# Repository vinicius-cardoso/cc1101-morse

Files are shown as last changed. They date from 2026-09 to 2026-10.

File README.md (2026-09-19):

# CC1101 Morse

A handheld Morse transceiver. Key it and the characters go out over 433 MHz;
leave it idle and it decodes what another unit sends back.

Press the key. The device times your dots and dashes, sounds a sidetone so you
hear what you send, keys the CC1101 in step, and prints the decoded letter over
serial. Point a second one at it and the two talk to each other.

The design goal is a board simple enough to make at home: **single layer,
through-hole only, no jumper wires**. There is no display — output is the buzzer
and the serial monitor — and that constraint is what keeps everything else
small.

<p align="center">
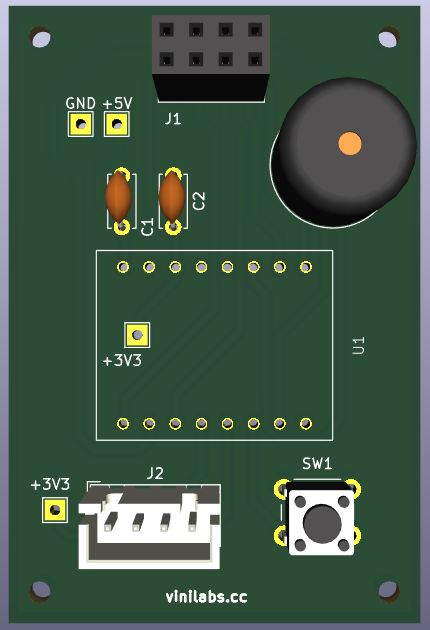
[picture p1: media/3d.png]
Rendered view of the assembled board
  
</p>

## Why it is simple

What the board carries is one module on a socket, a button, a buzzer, two
capacitors, two test points and two breakout headers — plus the MCU. None of it
surface-mount. That routes on a single face with no crossings to resolve.

| | |
|---|---|
| Layers | **1** |
| Vias | **0** |
| SMD parts | **0** |
| Jumper wires | **0** |
| Parts to solder | **11** |
| Display | serial + buzzer |

Zero SMD means the board can be hand-soldered from the underside with a plain
iron, and the fiber laser only ever etches one face — no two-sided
registration.

## Hardware

| Part | Role |
|---|---|
| ESP32-C3 Supermini | the brain — timing, decoding, radio, everything |
| CC1101 module | 433 MHz transceiver, socketed |
| Momentary key | Morse input |
| Passive buzzer | sidetone on transmit, audio on receive |
| SSD1306 OLED | *optional* — decoded text, plugs into `J2` |

Everything runs at **3.3 V**. The CC1101 is natively 3.3 V and so is the
ESP32-C3, so the supply is just the Supermini's onboard regulator — no boost
converter, no level shifter, no charge circuit.

### Pin budget — 8 of 13 GPIOs

| Function | Pins |
|---|---|
| CC1101 (SCK, MISO, MOSI, CS, GDO0, GDO2) | 6 |
| Morse key | 1 |
| Buzzer | 1 |
| **Total** | **8 — 5 spare** |
| *OLED (I²C, optional, off-board)* | *2 of the 5* |

See `docs/hardware.md` for the wiring detail.

## Transmit and receive

The CC1101 sends Morse as **OOK** — on-off keying, the carrier simply switched on
for a mark and off for a space. That is what Morse *is* on a radio, and it means
the transmitted signal is the key line itself: no packet format, no framing, no
preamble.

Receiving is the same idea backwards. The CC1101 is put in async serial mode,
where GDO0 goes high whenever the carrier is present, and the firmware times that
pin exactly the way it times the key. One decoder serves both directions.

> [!WARNING]
> **Never key the transmitter with the antenna unscrewed.** With nothing to
> radiate into, power reflects back into the PA and can damage it. For bench
> testing without emitting, use a 50 Ω dummy load in place of the whip.

> [!IMPORTANT]
> The legal position for 433 MHz short-range transmission in Brazil (ANATEL) has
> not been researched. Do that before transmitting outside a dummy load — see
> `docs/roadmap.md` phase 4.

## Power

USB-C, from the ESP32-C3 Supermini's own port. No battery, no charger, no boost,
no battery-sense divider — the board has **zero power components**.

Going portable later means wiring a cell and a TP4056 to the Supermini's
`5V`/`GND` pins. Nothing else changes, because nothing on the board wants more
than 3.3 V — so no boost converter is involved.

## On the bench

<p align="center">
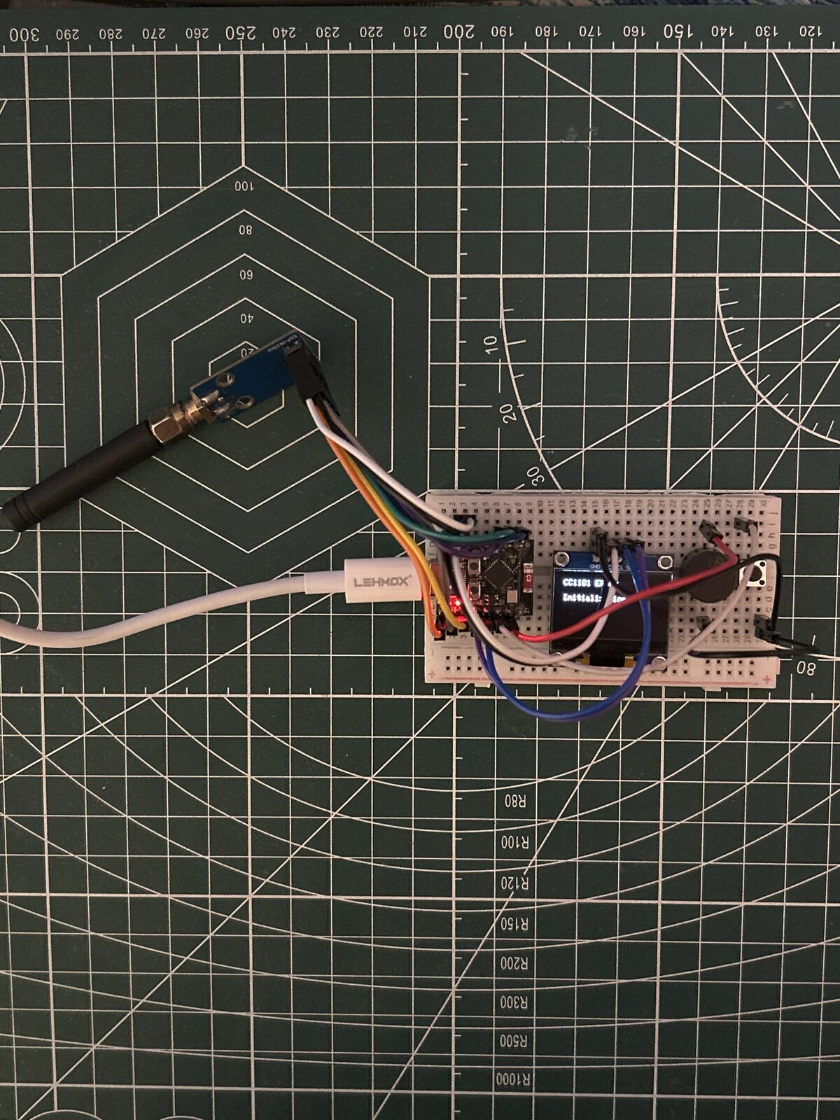
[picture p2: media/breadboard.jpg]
Breadboard prototype: ESP32-C3 Supermini, CC1101 with whip antenna, SSD1306 OLED, buzzer and key
  
</p>

The prototype, before the PCB exists: ESP32-C3 Supermini, the CC1101 with its
whip screwed on, a microswitch standing in for the key, a buzzer, and an
SSD1306 OLED on GPIO8/GPIO9.

**The OLED is optional.** `docs/decisions.md` §1 chose no display, and §7 kept
GPIO8/GPIO9 free so one could be added anyway; the board now brings them out on
`J2`, a 4-pin socket a module plugs straight into. The firmware supports a
display without requiring one:
`display.cpp` probes the I²C bus at startup, and if nothing answers, every
display call becomes a no-op. One binary runs with a screen and without.

## The board

<p align="center">
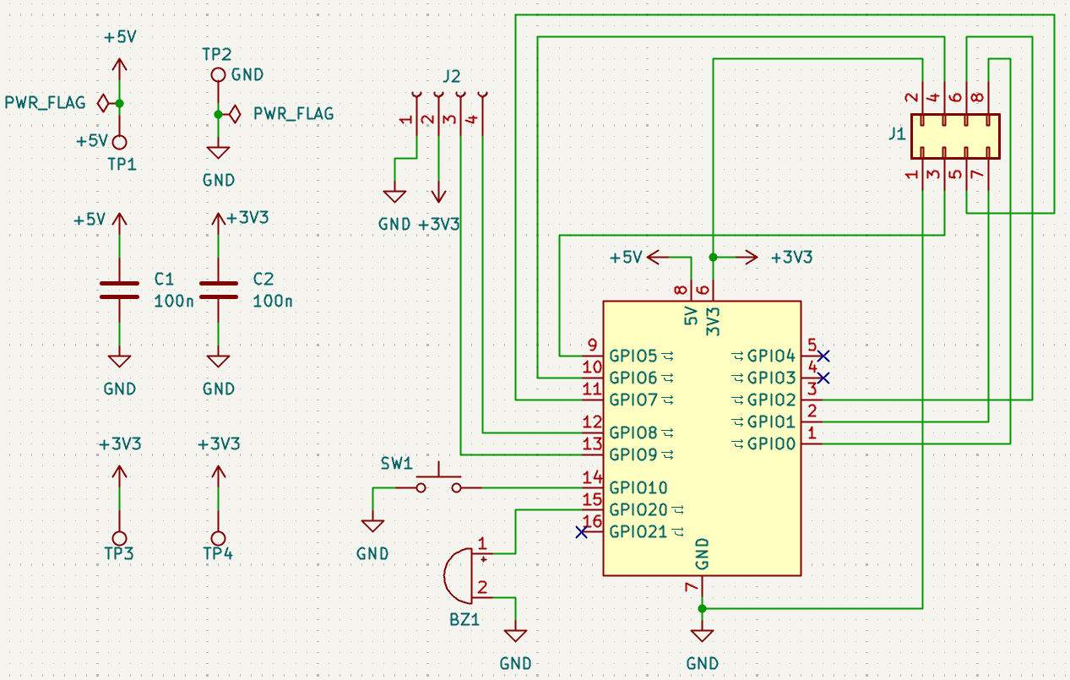
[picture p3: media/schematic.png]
Schematic: ESP32-C3 Supermini, CC1101 socket, key and buzzer
  
</p>

The CC1101 plugs into `J1`; `SW1` is the key and `BZ1` the buzzer. `C1`
decouples the `+5V` input to the Supermini's regulator, `C2` the `+3V3` rail at
the radio itself, and `TP1`/`TP2` are probe points for `+5V` and ground. `J2` is
a 4-pin socket for an optional display, with `TP3`/`TP4` a wire link that
completes its `+3V3` — see `docs/decisions.md` §14.

<p align="center">
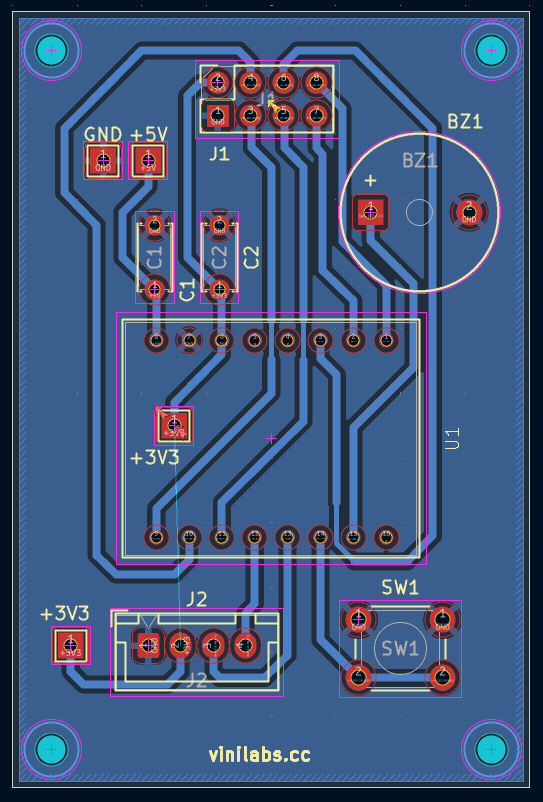
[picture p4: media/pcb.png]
PCB layout: single layer, through-hole, ground pour
  
</p>

All copper is on the **back** — no vias, no front-side traces. The stock is
single-sided, so components sit on the bare face and are soldered on the copper
face, which is the normal way to build through-hole on one layer.

Ground is the pour filling the board rather than a routed net, which is what
makes single layer work: the net that touches every part never has to be
threaded past the others. See `docs/decisions.md` §10.

Four M2 mounting holes, one per corner. Board is 40 × 60 mm.

## Repository layout

```text
.
├── bom/          # bill of materials
├── docs/         # design decisions, hardware notes
├── firmware/     # Arduino sketch (firmware/cc1101-morse/)
├── hardware/     # KiCad project, datasheets
├── mechanical/   # Onshape exports, case STEP/STL
└── media/        # reference images, photos
```

## Toolchain

- **KiCad** for the PCB (`hardware/kicad/`), exported to DXF for the laser —
  see `docs/fabrication.md`
- **Onshape** for the case, exported to `mechanical/`
- **Fiber laser** to engrave the copper
- **Arduino** for firmware (`firmware/cc1101-morse/`)

Keep editable sources as the source of truth: `.kicad_pro`, `.kicad_sch`,
`.kicad_pcb`, `.ino`, native CAD.

Generated manufacturing output lives in `exports/` and **is committed** —
`hardware/kicad/cc1101-morse/exports/` holds the DXF and drill files the laser
takes. They are derivatives, but a repo whose point is that you can make the
board should carry what the machine eats, without needing KiCad installed to
get it. Regenerate after any board change: `docs/fabrication.md` has the
commands.

## Status

**PCB done.** Routed by hand on one layer, no vias, ground poured — all copper
on the back, since the laminate is single-sided. DRC clean: 0 unconnected,
0 parity errors. DXF and drill files are exported for the laser; see
`docs/fabrication.md`, and **mind the mirror**. Not etched yet.

**The radio works.** On the breadboard the CC1101 answers over SPI
(`PARTNUM 0x0`, `VERSION 0x14`), and `send SOS SOS SOS` at 5 wpm was received on
an RTL-SDR in AM at 433.92 MHz. Key, decoder, buzzer and OLED all confirmed.

Next is phase 2 in `docs/roadmap.md` — a second unit, so two boards talk to each
other.

## Licence

GPL-3.0 — see `LICENSE`.

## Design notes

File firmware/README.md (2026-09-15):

# Firmware

Arduino sketch for the ESP32-C3 Supermini. Open
`cc1101-morse/cc1101-morse.ino` in the Arduino IDE, select **ESP32C3 Dev
Module**, and upload over USB.

> [!IMPORTANT]
> **Set `USB CDC On Boot` to `Enabled`.** It is *disabled* by default, and with
> it off `Serial` goes to the UART pins instead of the USB port — the sketch
> runs, prints into the void, and the serial monitor shows nothing at all. Every
> diagnostic in this firmware is a serial command, so without it you are blind.
>
> From the command line that is:
> ```sh
> arduino-cli compile --fqbn esp32:esp32:esp32c3:CDCOnBoot=cdc \
>   --libraries ~/hardware/arduino/libraries cc1101-morse
> arduino-cli upload -p /dev/ttyACM0 \
>   --fqbn esp32:esp32:esp32c3:CDCOnBoot=cdc cc1101-morse
> ```

The CC1101 is driven directly — no radio library. The **optional** OLED needs
`Adafruit_SSD1306` and `Adafruit_GFX`; if you do not have them, set
`DISPLAY_ENABLE 0` in `display.h` and the sketch builds without them.

## It runs with nothing attached

`radio.h` defaults to `RADIO_SIMULATE 1`: SPI is never touched and keying is
logged to the serial monitor instead of driving a chip. Key timing, decoding,
adaptive speed and the sidetone all work identically, so the whole firmware can
be developed and exercised on a bare Supermini — or on a Supermini with just a
button and a buzzer.

Set it to `0` once the CC1101 is wired.

You can also drive everything from the serial monitor with no key wired at all.
Type `help` for the command list.

## Files

| File | What it is |
|---|---|
| `cc1101-morse.ino` | main loop, serial commands, TX/RX arbitration |
| `morse_event.h` | the event vocabulary shared by both sources |
| `morse_tree.h` | the Morse tree, and letter ↔ code tables |
| `key.{h,cpp}` | debounce, dot/dash classification, adaptive speed |
| `radio.{h,cpp}` | CC1101 as an OOK carrier switch, both directions |
| `decoder.{h,cpp}` | events in, letters out |
| `sidetone.{h,cpp}` | the buzzer, at two pitches |
| `display.{h,cpp}` | optional SSD1306 OLED — absent by default |

## The shape of it

The design rests on one idea, and it is worth stating before reading the code:

**A dot is a dot whether a finger made it or a carrier did.**

`key.cpp` times a button. `radio.cpp` times a pin the CC1101 drives. Both emit
the same `MorseEvent` values, so `decoder.cpp` takes either one and never asks
which — the two decoder instances in the sketch are the same class with
different labels.

That is why receive cost so little to add. It is a second *producer*, not a
second decoder, and the tree walk, the letter commit, the gap handling and the
message buffer are all written once.

```
  key.cpp   ──┐
              ├──▶  MorseEvent  ──▶  decoder.cpp  ──▶  letters
  radio.cpp ──┘
```

## Why the event type has its own header

`morse_event.h` holds nothing but an enum, which looks like over-organisation
until you notice it is what lets `key.cpp` and `radio.cpp` stay strangers to
each other. Neither includes the other; both include the vocabulary. Putting
`MorseEvent` inside `key.h` would have made the radio depend on the key for no
reason other than where the type happened to be declared.

## The OLED is optional, and detected at runtime

The PCB has no display (`docs/decisions.md` §1), but GPIO8/GPIO9 were kept free
so one could be wired anyway (§7). `display.cpp` serves both cases from one
binary.

**It probes rather than assumes.** `Display::begin()` does a single-address I2C
probe at 0x3C. If nothing answers, `present_` stays false and every subsequent
call returns immediately — no retry loop, no timeout, no blocking. The buzzer and
serial output carry on exactly as before.

That is why there are no `#ifdef`s scattered through the sketch: the no-op path
is a runtime property of one object, not a compile-time variant of the whole
firmware. Plugging a screen into a finished board is a thing you can just do.

`DISPLAY_ENABLE 0` is a separate escape hatch, for building without the Adafruit
libraries installed. It compiles the module down to empty stubs.

**Wiring:** SDA to GPIO8, SCL to GPIO9, 3V3 and GND. Address 0x3C.

## Is your buzzer passive or active?

The firmware needs a **passive** buzzer — the kind that is just a piezo element
and plays whatever `tone()` drives it with. An active buzzer has its own
oscillator and plays one fixed note regardless, which collapses the 700 Hz and
550 Hz sidetones into the same sound and loses the distinction between what you
are sending and what is arriving.

They look identical, and listings rarely say which is which. Type `buzzer` at
the serial monitor:

| What you hear | What you have |
|---|---|
| pitch climbs 400 → 1200 Hz | **passive** — correct part |
| one steady note | **active** — wrong part |
| silence | not wired, or wired backwards |

It then plays 700 Hz and 550 Hz back to back. On a passive buzzer those are
obviously different notes; if they sound the same, it is active.

## Things worth knowing before changing it

**The radio stays in TX for `TX_HANG_MS` after you stop keying.** Switching modes
costs a calibration, so doing it per symbol would put that latency inside every
dot and smear the timing. The hang time trades a moment of deafness for clean
keying.

**The buzzer has an owner.** Whichever source keys it first holds it until it
releases. Letting your own key interrupt an incoming signal would chop up what
you are copying, which is backwards.

**Received marks shorter than `RADIO_RX_MIN_MARK_MS` are discarded.** 433 MHz is
full of garage doors and car fobs, and async mode has no sync word or CRC to
reject them. The threshold is a plausibility filter and nothing more — it cannot
tell a doorbell from a dash, only a 3 ms blip from a symbol. **It is a guess
until it has been tuned against the real band.**

**The message buffer is a fixed array, not a `String`.** This runs for hours
between resets, and heap fragmentation on a microcontroller is a slow, confusing
failure. When it fills, the oldest half is dropped.

## Testing without a second radio

Two units talking is the real test (see `docs/roadmap.md` phase 2), but before
that:

- `send SOS` transmits a known string, so a receiver — an SDR dongle, or a second
  unit — has something predictable to show.
- `status` reads `PARTNUM` / `VERSION` off the chip. **This is the first thing to
  run on newly wired hardware:** a sane answer (`0x00` / `0x14`) means SPI works,
  which separates wiring problems from radio problems. Anything else is almost
  always MISO/MOSI swapped or a module whose pin order differs from the assumed
  one.
- `power 0` drops TX power for bench work.

> [!WARNING]
> Fit a 50 Ω dummy load before any transmit test. Keying with nothing attached
> reflects power back into the PA and can damage it — and the whip cannot be used
> until the ANATEL question in `docs/roadmap.md` is settled.

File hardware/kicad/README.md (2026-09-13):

# KiCad

The KiCad project lives in `cc1101-morse/`, alongside `libraries/`.

`libraries/` holds the ESP32-C3 Supermini symbol and footprint, which the stock
KiCad libraries do not carry. Nothing else is needed from a custom library: the
CC1101 is a
socketed module represented by a generic `Conn_02x04_Odd_Even`, and everything
else is a stock KiCad part.

## Before drawing anything

Two things from `docs/hardware.md` that are easy to get wrong and expensive to
discover late:

1. **Check the CC1101 module's silkscreen** against the pin table in
   `docs/hardware.md` before routing. Pin order varies by module revision, and
   crossing VCC and GND destroys the module — on a board that is already etched.
   Check its **gender** too: the module on hand has male pins, so the board
   carries a female `PinSocket_2x04`. A `PinHeader` footprint has a different
   drill size and will not fit.

2. **This board is single-layer and through-hole only.** That is a design
   constraint, not a default to relax when routing gets awkward. If a net seems
   to need a jumper, the placement is wrong — see `docs/decisions.md` §3. The
   placement rules that make it work:

   - CC1101 socket at the board edge, SMA pointing outward.
   - Supermini directly beside it, so the six-trace SPI bundle is short.
   - Every ground-connected part at the perimeter; ground routes around the edge
     as a trace with short stubs inward, **not** as a pour.

## Footprints

All through-hole. The full table is in `docs/hardware.md` § KiCad reference —
`SW_PUSH_6mm`, `Buzzer_12x9.5RM7.6`, `PinSocket_2x04_P2.54mm_Vertical`,
`PinHeader_1x02_P2.54mm_Vertical`, `C_Disc_D5.0mm_W2.5mm_P5.00mm`.

## What to commit

Sources, not derivatives: `.kicad_pro`, `.kicad_sch`, `.kicad_pcb`, and any local
library files. The `.gitignore` already excludes backups, autosaves, the KiCad 10
`.history/` store, and generated gerbers — put manufacturing output in an
`exports/` directory if it needs keeping.

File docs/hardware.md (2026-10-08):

# Hardware notes

## Block diagram

```
   [KEY] ──────▶ ┌──────────────┐            ┌──────────┐
                 │  ESP32-C3    │ ──SPI───▶  │  CC1101  │ ──▶ SMA ──▶ whip
   [BUZZER] ◀─── │  Supermini   │ ◀──GDO0──▶ │  module  │
                 │              │ ╌╌GDO2╌╌╌  │          │   (wired, unused)
                 └──────────────┘            └──────────┘
                        │
                    USB-C (power + serial)
```

Everything on the board is 3.3 V. The ESP32-C3 Supermini's onboard regulator
supplies the CC1101 directly; there is no boost, no level shifter and no charge
circuit. That is the whole supply design.

The ESP32-C3 does all decision-making: key timing, dot/dash classification, tree
walking, letter identification, gap detection, radio keying, sidetone, and
decoding the received signal. The CC1101 is a dumb carrier switch in both
directions — see *OOK and why there is no packet format* below.

## Pin assignment (ESP32-C3 Supermini)

The Supermini breaks out GPIO 0–10, 20, 21 — 13 usable pins.

| GPIO | Function | Socket pin | Notes |
|---|---|---|---|
| 6 | CC1101 MOSI | 3 | |
| 5 | CC1101 SCK | 4 | |
| 2 | CC1101 MISO | 5 | |
| 7 | CC1101 GDO2 | 6 | wired, unused — see below |
| 0 | CC1101 GDO0 | 7 | TX key out / RX data in |
| 1 | CC1101 CSN | 8 | |
| 10 | Morse key | — | `INPUT_PULLUP`, active low |
| 20 | Buzzer | — | sidetone |

**Total: 8 of 13 — 5 spare (GPIO3, 4, 8, 9, 21).**

Listed in socket-pin order, because that is the order the wiring follows.

**The SPI assignment was chosen by the layout, not by the chip.** Every SPI line
here is bit-banged, so any GPIO serves, and the mapping was picked by searching
for the one whose traces do not cross. On a single-layer board a crossing is not
a nuisance — it is a trace that cannot be routed at all. See
`docs/decisions.md` §9.

### GDO2 is wired but not used

Nothing in the firmware reads it. Keying and carrier detection both run on
GDO0, and a second status pin adds nothing to the current design.

It is connected anyway because the pin cost nothing and the alternative was
discovering a use for it after the board was etched. A trace on an unpopulated
net is free; adding one to a finished single-layer board is not.

The use worth keeping in mind is **carrier sense** (`IOCFG2 = 0x0E`): the chip
asserts the pin when RSSI crosses a threshold, giving a hardware squelch. That
would let the receiver reject band noise *before* it reaches the timing code,
which is the weakest part of the RX path today — see *OOK and why there is no
packet format* and `RADIO_RX_MIN_MARK_MS` in `firmware/cc1101-morse/radio.h`.

Until then it is configured three-state (`0x2E`) and held as an input on the
ESP32-C3 side, so neither chip drives it.

GPIO8/GPIO9 are the strapping pins and the I²C defaults, and they stayed free
even though using them would have given a shorter route: the crossing-free search
was deliberately restricted to GPIO0–7 so an I²C peripheral — a small OLED for
the decoded text — remains possible. GPIO3, GPIO4 and GPIO21 are spare too.

These are final — the board is routed against them. Changing one now means
rewiring the schematic, re-routing, and editing `radio.h` to match.

## Power supply

**USB-C only.** The ESP32-C3 Supermini has a USB-C socket and an onboard 3.3 V
regulator. Plug it in and the board runs.

| Rail | Source | Feeds |
|---|---|---|
| `+3V3` | Supermini onboard regulator | CC1101, buzzer, key pull-up |
| `GND` | — | everything |

This is a genuine simplification rather than a deferral. Nothing on the board
wants more than 3.3 V, so there is no second rail to generate and no converter
to calibrate — the two failure modes that a mixed-voltage supply brings with it.

### Going portable later

There is **no battery header on the board** — the option was considered and left
off, since a cell can be soldered to the Supermini's own `5V`/`GND` pins if it is
ever wanted.

To go portable: a LiPo cell and a TP4056 charge module wire to these two
pins and nothing else changes. The CC1101 and ESP32-C3 are both 3.3 V, so a
3.7 V cell feeds `VIN` directly and the onboard regulator handles it — **no
boost converter needed**.

If that happens, add a resistor divider into a spare ADC pin (GPIO21 is free)
for a charge readout. Not on the board now:
an unpopulated divider is two more parts and two more traces for a feature that
does nothing while the board runs on USB.

## Power budget

There is no battery, so this only sizes the USB draw.

| Load | Draw |
|---|---|
| ESP32-C3 active | ~30 mA |
| CC1101 RX | ~16 mA |
| CC1101 TX @ 10 dBm | ~35 mA |
| Buzzer | ~20 mA |

- **Receive (idle listening): ~46 mA**
- **Transmit with sidetone: ~85 mA**

Any USB port supplies this without thinking about it. Worth recording because it
sets the cell size *if* the battery option is ever taken: 85 mA worst case means
a 1000 mAh cell runs roughly 12 hours. With no boost converter in the chain that
figure is real rather than derated.

## OOK and why there is no packet format

The CC1101 is normally used as a packet radio: you hand it bytes, it adds a
preamble, sync word and CRC, and the receiver hands bytes back. **None of that is
used here.**

Morse on a radio is **OOK** — on-off keying. The carrier is switched on for a
mark and off for a space, and the *timing of those switches is the message*.
There is nothing to packetise: the dot/dash structure already encodes everything,
and wrapping it in a frame would mean buffering the operator's keying, sending it
as a block, and replaying it at the far end. That destroys the thing that makes
Morse Morse, which is that it is live.

So the chip is configured as a carrier switch in both directions:

- **Transmit** — `MOD_FORMAT = OOK`, `GDO0` configured as the TX data input in
  async transparent mode. The firmware drives GDO0 high and the carrier comes on;
  drives it low and it goes off. Exactly like keying a transmitter.
- **Receive** — same mode, opposite direction. GDO0 becomes an output that
  follows the detected carrier, and the firmware times that pin with the same
  code that times the key.

One decoder serves both, which is the nice consequence: a received mark and a
keyed mark are the same event with a different source, so `decoder.cpp` does not
know or care which it is handling.

### Register settings that matter

| Register | Value | Why |
|---|---|---|
| `MDMCFG2` | `0x30` | OOK modulation, no sync word, no Manchester |
| `PKTCTRL0` | `0x32` | async serial mode — no packet engine at all |
| `IOCFG0` | `0x0D` (RX) / `0x2E` (TX) | GDO0 = serial data out / high-impedance for TX input |
| `IOCFG2` | `0x2E` | GDO2 three-state — wired to GPIO7 but unused |
| `FREQ2/1/0` | 433.92 MHz | the band centre |
| `PATABLE` | `0xC0` | +10 dBm; lower it for bench work |

The full init table lives in `firmware/cc1101-morse/radio.cpp` — that is the
authoritative copy, and it carries per-register comments.

> [!NOTE]
> Async mode means **no error correction and no addressing**. Anything on the
> channel keys the receiver, including garage doors, weather stations and car
> fobs, which are all over 433 MHz. Expect noise-triggered garbage between real
> letters; `decoder.cpp` filters implausibly short marks, but it cannot
> distinguish a neighbour's doorbell from a deliberate dash.

## CC1101 module and antenna

The module is the **V2.0 SMA variant**, marked `433M`, with a gold SMA female
socket on the board edge. It ships with a short black whip antenna carrying a
male SMA plug, which **screws onto** that socket.

The antenna is therefore **detachable, not built in** — the two simply come in
the same bag. Nothing to buy, but the mechanical design has to account for it:

- The SMA socket sticks out from the module's edge and is rigid. It sets a hard
  constraint on where the CC1101 can sit inside the case.
- The case needs either an opening for the whip, or an internal antenna position
  with the whip removed. Antennas do not work well inside a sealed enclosure,
  especially near a copper ground plane.
- A panel-mount SMA extension (pigtail) is the usual fix: socket on the case
  wall, short coax to the module. Adds a part but frees the module's placement.
- The whip is removable, so it can be unscrewed for storage — worth designing for
  if the device is meant to be pocketable.

**Never key the transmitter with the antenna unscrewed.** With nothing to radiate
into, power reflects back into the PA and can damage it. For bench testing
without emitting, use a 50 Ω dummy load in place of the whip.

### The module is socketed, not soldered

The CC1101 is removable. It is an expensive part relative to the rest of the
board, it is the part most likely to be swapped (different band, different module
revision), and it carries the rigid SMA connector that constrains the case — all
reasons to keep it removable.

**The module has male pins, so the board carries a female socket** (`J1`, a 2×4
pin socket). The module plugs down into it. Worth stating explicitly because the
two footprints have different drill diameters and are not interchangeable — the
wrong one means a board that is etched and drilled but will not accept the part:

| | Board carries | Drill |
|---|---|---|
| `PinSocket_2x04` | a female socket body — **this board** | larger |
| `PinHeader_2x04` | male pins | smaller |

Check the module in hand rather than trusting this table: revisions vary, and
some ship with female headers instead.

| Socket pad | CC1101 | ESP32-C3 |
|---|---|---|
| 1 | GND | `GND` |
| 2 | VCC | `+3V3` |
| 3 | GDO0 | GPIO5 |
| 4 | CSN | GPIO6 |
| 5 | SCK | GPIO7 |
| 6 | MOSI | GPIO2 |
| 7 | MISO/GDO1 | GPIO1 |
| 8 | GDO2 | GPIO0 — wired, unused |

**This is the module's own numbering**, taken from its datasheet — GND on pin 1,
VCC on pin 2, then GDO0, CSN, SCK, MOSI, MISO, GDO2. Not every CC1101 board
numbers them this way; read the silkscreen of the one you are plugging in.

The GPIO column is a consequence, not a choice. The board's traces were routed
for a crossing-free single layer, and the module's pinout then decides which
function arrives at which GPIO. Since every SPI line is bit-banged, the firmware
simply names them to match — see `docs/decisions.md` §12.

Getting the supply pair backwards destroys the module, and on an etched board
that is not recoverable.

> [!NOTE]
> Pin order varies between CC1101 module revisions. Check the silkscreen on the
> module in hand against this table before routing — getting VCC and GND crossed
> destroys it.

## The optional OLED

The board has no display, but GPIO8/GPIO9 are free and the firmware drives an
SSD1306 on them if one is present — see `docs/decisions.md` §11.

| OLED pin | ESP32-C3 |
|---|---|
| VCC | `+3V3` |
| GND | `GND` |
| SDA | GPIO8 |
| SCL | GPIO9 |

Address 0x3C, 128 × 64. Most modules carry their own pull-ups; if yours does
not, add 4.7 kΩ from each line to 3V3.

**The board carries a 4-pin JST XH header for it**, `J2`, wired in this order:

| `J2` pad | Net | SSD1306 pin |
|---|---|---|
| 1 | `GND` | GND |
| 2 | `+3V3` | VCC |
| 3 | GPIO9 | SCL |
| 4 | GPIO8 | SDA |

`J2` is a **JST XH**, not a bare pin header: polarised, latching, and it will
not fall out when the board is handled. Note the pitch is **2.50 mm, not
2.54** — the pads sit off the board's grid, which is normal for this part.

**GND first, then VCC** — matching the module on hand. Other SSD1306 boards put
VCC first; check the silkscreen before plugging one in, because reversing that
pair destroys the display.

Note that `J2` is rotated 90° on the PCB, so pad 1 sits at the **right-hand**
end as the board is drawn. Pad numbers and left-to-right order are not the same
thing here.

The firmware probes for a display at startup and carries on without one, so
leaving `J2` unpopulated costs nothing.

> [!IMPORTANT]
> `+3V3` reaches `J2` through a **wire link between `TP3` and `TP4`**, not
> through copper. On one layer the rail could not get there without cutting the
> ground pour that the CC1101 depends on — see `docs/decisions.md` §14. Solder
> that link or the display gets no power.

## The buzzer must be passive

`tone()` generates a square wave at a chosen frequency. That requires a
**passive** buzzer, which is just a piezo element and sounds whatever it is
driven with. An **active** buzzer contains its own oscillator and plays one fixed
note whenever it has power — it ignores `tone()` entirely.

This matters because the buzzer is the only real-time output the device has. It
carries the sidetone on transmit *and* the received signal on receive, and being
able to shift pitch between the two is what makes it possible to tell them apart
by ear.

| Direction | Pitch | Why |
|---|---|---|
| Transmit (your key) | 700 Hz | classic CW sidetone |
| Receive (incoming) | 550 Hz | lower, so the two never blur together |

They are set in `firmware/cc1101-morse/sidetone.h`.

## Decoupling

Two 100 nF ceramics, doing different jobs on different rails:

| Cap | Rail | Job |
|---|---|---|
| `C1` | `+5V` | steadies the USB rail feeding the Supermini's regulator |
| `C2` | `+3V3` | local reservoir for the CC1101 |

**`C2` is the one that matters for the radio.** In TX the CC1101 draws ~35 mA,
but it switches that on and off at keying speed while `radio.cpp` bit-bangs SPI
alongside it — every mark is a step change in current. The regulator responds in
microseconds and the trace to the socket has inductance, so `C2` supplies that
first instant locally. Place it close to `J1` pin 1; a decoupling cap works by
being near, and the loop area between cap, supply pin and ground is what decides
whether it does anything.

Without it the board would very likely still work at these currents. The reason
to fit it anyway is the failure mode if it is needed and absent: intermittent
SPI errors or the radio dropping out *only while transmitting*, which is
unpleasant to diagnose.

`C1` is not the radio's cap and never was — it sits across the input rail near
`U1`, smoothing what arrives from USB.

## Key debounce

The key is a plain tactile switch to ground with `INPUT_PULLUP`, debounced in
firmware at 15 ms (`KEY_DEBOUNCE_MS` in `key.h`). No RC network on the board.

15 ms is comfortably shorter than the shortest meaningful Morse symbol: a dot at
the 30 WPM ceiling is 40 ms. A hardware debounce would be two more parts for no
benefit.

## KiCad reference

Verified against the KiCad 10.0.5 stock libraries.

### Symbols

| Part | Library | Symbol |
|---|---|---|
| Tactile switch | `Switch` | `SW_Push` |
| Buzzer | `Device` | `Buzzer` |
| Resistor / capacitor | `Device` | `R` / `C` |

### Symbols NOT in the stock libraries

Both are boards mounted on headers rather than bare chips, so represent each with
a generic connector sized to its pin count:

- **ESP32-C3 Supermini** — stock libs carry only the bare die and the WROOM
  modules, not this board. Use the local `ESP32-C3-SuperMini` library in
  `hardware/kicad/libraries/`.
- **CC1101 module** — socketed, not soldered. Use a generic
  `Connector_Generic:Conn_02x04_Odd_Even` symbol with the footprint
  `Connector_PinSocket_2.54mm:PinSocket_2x04_P2.54mm_Vertical`. No dedicated
  symbol is kept: the board only carries the socket, so a generic connector
  describes it accurately.

### Footprints — all through-hole

| Part | Footprint |
|---|---|
| CC1101 socket | `Connector_PinSocket_2.54mm:PinSocket_2x04_P2.54mm_Vertical` |
| ESP32-C3 Supermini | local `ESP32-C3-SuperMini.pretty` |
| Tactile switch | `Button_Switch_THT:SW_PUSH_6mm` |
| Buzzer | `Buzzer_Beeper:Buzzer_12x9.5RM7.6` |
| Battery header | `Connector_PinHeader_2.54mm:PinHeader_1x02_P2.54mm_Vertical` |
| Decoupling cap | `Capacitor_THT:C_Disc_D5.0mm_W2.5mm_P5.00mm` |

**Nothing is SMD.** Every part here is through-hole and soldered from the
underside, which is the easiest possible assembly and matches the single-layer
constraint — through-hole joints on a one-sided board are soldered on the side
*without* the components, so there is nothing to work around.

## Single-layer routing

The board routes on one face with **no jumper wires**. This is the design's main
claim, so it is worth recording why it holds.

There are four things to connect and only three real nets bundles:

- **SPI + GDO0 + GDO2** — six parallel signals from the Supermini to the CC1101
  socket.
  Both parts are headers with 2.54 mm pitch, so the five traces run as a straight
  bundle between them with nothing to cross.
- **Key** — one trace to a switch, plus ground.
- **Buzzer** — one trace, plus ground.
- **Power** — `+3V3` and `GND` to the socket.

Ground is the only net that reaches everything, and it is a **filled zone**
rather than a routed net — see `docs/decisions.md` §10. That is what makes the
rest fit on one face: every ground pad drops into the pour wherever it sits, so
the net that touches every part never has to be threaded past the others.

```
   ┌──────────────────────────────────┐
   │   ⊕  J1 (CC1101)          BZ1 ●  │   ← whole board is GND pour
   │      ▓▓▓▓▓▓▓▓                    │
   │   TP1 TP2                        │
   │   C1 ▬                           │
   │      ┌────────────────────┐      │
   │      │   ESP32-C3 (U1)    │      │
   │      └────────────────────┘      │
   │            ▢ SW1                 │
   │   ⊕                          ⊕   │   ← M2 holes at corners
   └──────────────────────────────────┘
            40 × 60 mm
```

As built: `J1` at the top edge so the module's SMA points off the board, `U1`
centred beneath it, `SW1` below that, and the buzzer top-right. Four M2 holes
at the corners.

Placement rule for layout: **keep the CC1101 socket on the board edge with the
SMA pointing outward**, and put the Supermini directly beside it so the SPI
bundle is as short as possible. SPI at the CC1101's clock rates is not
especially fussy, but a short bundle also means a short board.

## Design rules

| Setting | Value |
|---|---|
| Track width | 0.6 mm, dropping to 0.4 mm past `U1`'s pads |
| Clearance | 0.4 mm |
| Net classes | none — everything on `Default` |

**Why two widths.** 0.6 mm is the default: wider copper survives laser etching
and handling better, and the board has room for it almost everywhere.

Almost. `U1`'s pads sit on a 2.54 mm grid, and a 0.6 mm track threading between
them leaves exactly 0.30 mm to each pad — under the 0.40 mm rule. Eight short
segments are therefore narrowed to 0.4 mm for the two or three millimetres they
spend passing a pad, and widen again on the other side.

That is the right place to give the width back. The reason for widening is
robustness over long runs across open copper; a 2 mm stretch hemmed in by pads
on both sides is the best-supported copper on the board.

**No net classes.** They exist to give groups of nets different physical rules,
and nothing here needs different rules: eight digital signals at Morse speeds,
plus power and ground. The SPI clock runs at a few hundred kHz and GDO0 switches
at the speed of a hand. Nothing is fast, high-current, or impedance-controlled.

0.4 mm is wider than a fab house's usual 0.25 mm default, which is the right
direction for laser etching — the cut widens as it bites, so the copper that
survives is narrower than drawn, and roughness at the trace edge matters more
than it would with photolithography. The board has twelve nets and acres of
spare copper, so the margin is free.

**Worth considering later: widen `GND` to ~0.8 mm.** Ground is routed as a
perimeter trace rather than a pour (see *Single-layer routing* above), which
makes it a long thin strip near the board edge carrying every return current
and absorbing whatever handling the board gets. The electrical case is nil at
85 mA; the mechanical one is real, and a partially-lifted ground trace fails
intermittently rather than cleanly — the worst kind of fault to chase. One net
class, no routing cost.

## Fabrication

Copper engraved with a fiber laser. Relevant consequences:

- **One face only.** There is nothing on the back, so the board goes on the
  laser once and comes off finished — no two-sided registration, no alignment
  holes.
- **Trace count is low** — twelve nets, and ground is a pour rather than traces.
  Every trace is engraving time and a potential defect.
- **2.54 mm pitch everywhere.** Every part is a through-hole header, switch or
  buzzer, all on a 2.54 mm or wider grid. That sidesteps needing to characterise
  the laser's minimum trace/space entirely — any fiber laser holds this
  comfortably.
- **Drilling:** roughly 34 holes (2×8 socket, 2×8 Supermini headers, 4 switch,
  2 buzzer, 2 battery header). All 0.8–1.0 mm, no fine work.

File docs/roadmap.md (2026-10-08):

# Roadmap

Ordered so that each step produces something testable, and so the parts that are
still undecided stay off the critical path.

The ANATEL question blocks transmitting on air, so everything up to and including
the PCB is arranged to happen without needing it answered — bench work into a
dummy load is legal and proves the whole design.

## Phase 0 — firmware without hardware

The sketch runs on a bare ESP32-C3 Supermini with nothing else attached.
`radio.h` defaults to `RADIO_SIMULATE 1`, which prints what it would key instead
of driving the chip.

- [x] Key timing: debounce, classify dot vs dash by duration.
- [x] Tree walk and letter decode → serial.
- [x] Adaptive timing, so the dot/dash threshold follows the user's speed.
- [x] Sidetone keyed with the input.
- [ ] Flash it, key a button on GPIO10, confirm letters come out right.
- [ ] Check the adaptive unit settles sensibly for a beginner's keying. The
      1/8 pull rate is a guess and has never been tested against a real hand.

## Phase 1 — the radio on a breadboard

No PCB needed. Supermini + CC1101 module on jumper wires.

- [ ] Wire the CC1101 per the pin table in `docs/hardware.md`. **Check the
      module's silkscreen against it first** — pin order varies by revision and
      crossing VCC/GND destroys the module.
- [ ] Set `RADIO_SIMULATE 0`. Confirm SPI talks: read the `PARTNUM` and `VERSION`
      status registers and check they are sane (`0x00` / `0x14`). This is the
      first thing to do and it isolates wiring problems from everything else.
- [ ] **Fit a 50 Ω dummy load**, not the whip. Everything below happens into the
      dummy load until ANATEL is settled.
- [ ] Transmit: key the radio and confirm the carrier appears. An SDR dongle or
      a second CC1101 is enough to see it.
- [ ] Receive: put the module in RX, confirm GDO0 follows an incoming carrier.
- [ ] Tune `RADIO_RX_MIN_MARK_MS` against the real noise floor. 433 MHz is busy —
      garage doors, weather stations, car fobs — and the current value is a
      guess.

## Phase 2 — two units talking

This is the milestone that makes the device a device rather than a demo.

- [ ] Build a second breadboard unit.
- [ ] Key one, decode on the other. Both into dummy loads, sitting next to each
      other — at a few centimetres the leakage is plenty of signal.
- [ ] Confirm the RX sidetone pitch (550 Hz) is distinguishable from your own
      keying (700 Hz) by ear, which is the point of having two pitches.
- [ ] Full duplex-ish behaviour: what happens if both key at once? Decide whether
      that needs handling or is just an operator problem, the way it is on a real
      band.

## Phase 3 — PCB

Single layer, through-hole only. See `docs/hardware.md` § Single-layer routing.

- [x] Schematic in KiCad. ERC clean, netlist verified against the pin table.
- [x] Placement: CC1101 socket at the top edge, SMA pointing off the board;
      Supermini centred beneath it; key below that; buzzer top-right.
- [x] Route on one face. **No vias, no jumper wires.** Took a pin reassignment
      to get there — see `docs/decisions.md` §9.
- [x] Ground as a filled zone rather than a routed net — `docs/decisions.md` §10.
- [x] Four M2 mounting holes, one per corner. Board is 40 × 60 mm.
- [ ] **Refill the zone (`B`) and re-run DRC until clean.** A zone that has not
      been refilled since the traces were laid reports a clearance violation
      against every net it touches — DRC is meaningless until this is done.
- [ ] Check no trace runs through a mounting hole. The autorouter could not read
      the holes' keepout areas, so it routed without knowing they exist.
- [ ] Export DXF for the laser — `docs/fabrication.md`. **Watch the polarity:**
      the copper layer is what must *remain*, and a laser removes what it marks.
- [ ] Engrave, drill (46 holes, six sizes), populate, test.

## Phase 4 — on the air

- [ ] **Research ANATEL limits for 433 MHz short-range in Brazil. Blocking.**
      Nothing in this phase happens before this is answered.
- [ ] Swap the dummy load for the whip. Range test between two units.
- [ ] Characterise: how far, and how badly does the band's existing traffic
      corrupt reception in practice?

## Phase 5 — case

- [ ] Onshape model around the finished board.
- [ ] Opening for the SMA whip, or a panel-mount pigtail so the module's
      placement is not dictated by the antenna.
- [ ] Design for the whip being unscrewed for storage — it is detachable and the
      device is meant to be pocketable.
- [ ] Export STEP/STL to `mechanical/`.

## Ideas, unscheduled

- **I²C OLED** on GPIO8/9 showing decoded text, so the device is usable without a
  computer attached. The pin budget has five spare, so this costs nothing but the
  part — it is the most obvious next feature.
- **Beacon mode:** transmit a stored message on a timer. Useful for range
  testing alone.
- **Practice mode without the radio:** the device sends a letter to the buzzer,
  you copy it back on the key. Reverse training, no RF involved, so no
  regulatory question.
- **Store what you sent** and replay it, for reviewing your own fist.
- **Adjustable TX power** via `PATABLE`, exposed as a serial command — useful for
  bench work and for staying inside whatever limit ANATEL turns out to set.

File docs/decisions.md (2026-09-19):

# Design decisions

A record of what was chosen, what was rejected, and why. Written so the reasoning
survives — if a decision gets revisited, the tradeoff is here rather than being
re-derived from scratch.

## 1. No display

**Decision:** the device has no screen and no indicator panel. Output is the
buzzer and the serial monitor.

**Why:** a display is the single most expensive feature a board like this can
carry, and the cost is not the display itself — it is everything the display
drags in. A multiplexed LED panel needs a driver IC; the common drivers are 5 V
parts, so a 3.3 V MCU needs level shifting; 5 V from a battery needs a boost
converter; and the driver's addressing scheme rarely matches the physical
arrangement, which forces a second copper layer to resolve the crossings.

None of that exists here. The chain never starts.

**Tradeoff accepted:** you cannot read what you sent without a computer attached.
For a device whose purpose is keying Morse — where the operator is listening, not
looking — that is a smaller loss than it sounds. The buzzer carries the
information in real time, which is how Morse is meant to be received.

**Open, and cheap:** an I²C OLED on GPIO8/GPIO9 gives decoded text with two wires
and no driver IC, because it has its own controller. The firmware already
supports one (`display.cpp`) — see §11. The *board* still has no footprint for
it, which keeps §2 and §3 intact.

## 2. Through-hole only

**Decision:** every part on the board is through-hole. No SMD, not even passives.

**Why:**

- **Soldering.** On a single-layer board, through-hole parts are soldered from
  the face *without* components. There is nothing to work around, no tweezers,
  no reflow, no solder paste.
- **Laser.** Every footprint sits on a 2.54 mm or wider grid, which no fiber
  laser struggles with. Characterising the minimum trace/space stops being a
  prerequisite for starting.
- **Serviceability.** Parts can be desoldered and replaced with a plain iron.

**Tradeoff accepted:** a larger board, and 46 holes to drill. Both are cheap
here — the board is sized by the Supermini and the CC1101 module, not by the
passives, so going SMD would not shrink it much.

## 3. Single layer, no jumpers

**Decision:** route on one face, no jumper wires.

**Why it is possible:** there is very little to route. Twelve nets, seven parts:
six parallel traces between two headers, two signal traces to a switch and a
buzzer, and power. Nothing fights for the same space once the parts are placed
sensibly.

**What makes it work in practice:** ground is a **filled zone**, not a traced
net (see §10). That removes the net that touches everything from the routing
problem entirely, which is what lets the rest fit on one face.

**Rejected:** double-sided "because it is easier to route." It is, but it costs
two-sided laser registration and alignment holes for a board that does not need
it. Single layer is the point of this design; if the routing ever genuinely
requires a second layer, that is a signal the scope crept.

## 4. USB-C power, no battery

**Decision:** powered from the ESP32-C3 Supermini's own USB-C port. No battery,
and no header for one.

**Why:** the CC1101 and the ESP32-C3 are both 3.3 V natively, so there is no
second rail to generate. The Supermini's onboard regulator is the entire power
design — zero power components on the board.

**Why no battery now:** the board's first job is bench work — talking to a second
unit, testing into a dummy load, settling the ANATEL question. All of that
happens next to a computer, where USB is already connected for the serial monitor
anyway.

**Rejected:** fitting the battery now. It is a cell, a charge module, a switch,
and a sense divider — four parts and their traces — for a capability nothing
currently needs. Adding it later means soldering to the Supermini's `5V`/`GND`
pins, which needs no board change: nothing here wants more than 3.3 V, so no
boost converter is involved.

## 5. Transceiver, not just a transmitter

**Decision:** the device receives as well as transmits. Incoming carrier is
decoded to letters and played on the buzzer at a different pitch.

**Why:** it is nearly free. The CC1101 does OOK in both directions with the same
async configuration, and the decoder that times the key is *the same decoder*
that times the received signal — a mark is a mark whether a finger or a carrier
produced it. `decoder.cpp` does not know which source it is handling.

What it buys is that two boards talk to each other, which makes the device
testable without a second radio of any other kind, and useful as a pair.

**Tradeoff accepted:** in async mode there is no addressing and no error
correction, so anything on 433 MHz keys the receiver — garage doors, weather
stations, car fobs. Expect garbage between real letters. The decoder filters
implausibly short marks; it cannot tell a doorbell from a dash.

## 6. OOK async, not the packet engine

**Decision:** configure the CC1101 as a bare carrier switch (async serial mode,
`PKTCTRL0 = 0x32`), bypassing its packet engine entirely.

**Why:** Morse on a radio *is* OOK — carrier on for a mark, off for a space, with
the timing carrying the message. There is nothing to packetise. Using the packet
engine would mean buffering the operator's keying, transmitting it as a block,
and replaying it at the far end, which destroys the property that makes Morse
Morse: it is live. You hear the other operator's hand, their rhythm, their
hesitation.

**Consequence:** no CRC, no addressing, no retries. Accepted — see §5.

**Rejected:** packet mode with a Morse-shaped payload. More robust on paper, but
it turns a radio into a messaging protocol and the latency makes real-time
keying impossible.

## 7. GPIO8, GPIO9 and GPIO21 are kept free

**Decision:** the key sits on GPIO10, the buzzer on GPIO20, and the CC1101 on
GPIO0–7. GPIO3, GPIO4, GPIO8, GPIO9 and GPIO21 are left unconnected.

**Why GPIO8/GPIO9 specifically:** they are the strapping pins and the I²C
defaults, which makes them the least convenient pins to commit and the most
valuable to keep. An I²C OLED showing decoded text is the obvious future
addition (§1), and it needs exactly those two.

This cost something real: the crossing-free pin search in §9 found a solution
41 mm shorter when allowed to use them. The shorter route was not worth spending
the pins.

## 8. The buzzer carries two pitches

**Decision:** 700 Hz for your own keying, 550 Hz for received signal.

**Why:** the buzzer is the only real-time output the device has, and it has to
serve two directions at once. Two pitches make them distinguishable by ear
without looking at the serial monitor — which matters, because the whole point of
keying is not looking at a screen.

700 Hz is the classic CW sidetone pitch. 550 Hz is far enough below it to be
unmistakable and still comfortable.

**Requires a passive buzzer.** An active buzzer contains its own oscillator and
plays one fixed note, ignoring `tone()` entirely — which would collapse both
pitches into one and lose the distinction that justifies having them.

## 9. The SPI pin assignment was chosen by the router, not by hand

**Decision:** MOSI on GPIO6, SCK on GPIO5, MISO on GPIO2 — replacing an earlier
hand-picked GPIO2/3/4.

**Why:** the first autoroute attempt failed. Not marginally — it left a net
unroutable and stalled. The cause was not the router: the straight-line paths
between the connector and the MCU **crossed each other five times among seven
nets**, because the connector's left-hand pins were assigned to the MCU's
right-hand pins and vice versa.

On a two-layer board a crossing is a via. On a single-layer board it is a trace
that **cannot be routed at all**, so five crossings meant the assignment was
unroutable no matter how long the router ran.

**What makes the fix legal:** every SPI line here is bit-banged
(`radio.cpp`, `transfer_()`), not driven by a hardware SPI peripheral. There is
no fixed pin mapping to respect — any GPIO can carry any of these signals. So the
mapping is free, and the right way to pick it is to search for the permutation
with no crossings rather than to guess.

**The general lesson, worth keeping:** when an autorouter fails on a trivial
board, the placement or the assignment is wrong, not the router's settings. Count
the crossings before touching anything else — on one layer that number is a hard
bound on what is routable.

## 10. Ground is a filled zone

**Decision:** ground is a copper pour on `B.Cu`, not a routed net.

**Why:** ground is the net that touches everything — every part has a ground pin,
and they sit at opposite corners of the board. Routing it on a single layer means
threading one trace past every other trace, and it was the last thing the
autorouter failed on.

A pour makes the problem disappear: each ground pad drops into the fill wherever
it happens to sit, with nothing to route.

**Why the fragmentation worry did not apply:** the usual objection to a
single-layer pour is that signal traces cut it into islands. This board is
40 × 60 mm with about 15 thin traces concentrated in one corridor — there is far
more uninterrupted copper than there is trace, and the ground pads sit at the
edges where the fill is continuous. Dense boards have this problem; this one does
not.

**It also suits the process.** A fiber laser works by *removing* copper, so
leaving a large filled area is less etching than clearing it away. The pour is
faster to make than the alternative, not slower.

**Verification:** after filling, no GND pad should show a ratsnest line, and DRC
must be clean. A zone that has not been refilled since the traces were laid will
show clearance violations against every net — refill (`B`) before believing any
DRC result.

## 11. The OLED is supported in firmware but absent from the board

**Decision:** `display.cpp` drives an SSD1306 on GPIO8/GPIO9, but the PCB carries
no footprint, no connector and no I²C pull-ups for it.

**Why both at once:** §1 rejected a display because of what a display *drags in*
— a driver IC, a second voltage, a second copper layer. An I²C OLED brings none
of that: it has its own controller, runs at 3.3 V, and costs two wires. The
objection in §1 was never to pixels; it was to the support chain.

But putting it on the board would still cost a connector, four more holes, and a
cutout in a case that does not exist yet — for a part that is genuinely optional.

So the firmware supports it and the board does not require it. On a breadboard
you get decoded text; on the bare PCB you get the buzzer and the serial monitor,
which is what §1 signed up for.

**How absence is handled — runtime, not compile time.** `Display::begin()` probes
0x3C once. Nothing there, and every later call returns immediately. No retry, no
timeout, no blocking.

That choice matters more than it looks. A `#define` would have meant two
binaries, and the wrong one on the wrong board is a confusing failure. A runtime
probe means **one firmware image runs on both**, and plugging a screen into a
finished board works without recompiling anything.

**Tradeoff accepted:** a few hundred bytes of flash on boards that will never
have a display, and a dependency on two Adafruit libraries. `DISPLAY_ENABLE 0`
removes both if that ever matters.

## 12. The socket follows the module's pinout, and the firmware follows the socket

**Decision:** `J1`'s pads carry GND, VCC, GDO0, CSN, SCK, MOSI, MISO, GDO2 in
that order — the CC1101 module's own numbering — and `radio.h` names whichever
GPIO reaches each pad accordingly.

**Why this needed deciding at all:** the board was first drawn with a different
pin order, guessed rather than read off the module. Two things were wrong. The
supply pair was reversed, so plugging a module into the board would have applied
+3V3 to its GND pin. And all six signals were offset, so nothing would have
talked even if the module survived.

It was caught on the breadboard, where `status` reported
`PARTNUM 0xFF VERSION 0xFF` — MISO stuck high, the signature of a module that is
not driving the bus.

**Why the fix was cheap:** the SPI is bit-banged (`radio.cpp`, `transfer_()`), so
no pin is special. Once the socket matches the module, the firmware is six
`#define` lines. Nothing was re-routed for the signals.

The power pair was different — `+3V3` and `GND` are physical rails and cannot be
remapped in software, so that pair did need fixing on the board.

**The rule worth keeping:** read the pinout off the module in hand, not off a
datasheet found elsewhere, and get it into the schematic before routing. This
cost a full re-check of the board late, and would have cost a destroyed module
had it reached copper.

## 13. All copper is on the back, components on the front

**Decision:** traces and the ground pour live on `B.Cu`. Footprints stay on
`F.Cu`, so component bodies sit on the front.

**Why:** the laminate is single-sided — copper on one face, bare substrate on
the other. That is not a layer *choice*, it is what the material is. The
earlier design had copper on `F.Cu`, which describes a board whose copper is on
the component side; no such board was going to be made.

The build is the standard through-hole one: parts on the bare face, leads
through the holes, soldered on the copper face. Nothing about the routing
changed — the same 69 segments and the same pour, on the other side of the
board.

**Cost:** nothing electrically. Through-hole pads are defined on `*.Cu`, so they
already existed on both layers and needed no edit.

**What it does add is a way to ruin a board.** KiCad draws every layer from the
top, so a `B.Cu` export is a view *through* the laminate. Engraving it as
exported puts a mirrored image on the copper, and every footprint lands
reversed. The artwork has to be flipped before it reaches the laser — see
`docs/fabrication.md`, which carries the check for it.

## 14. One wire link, for `+3V3` to the display connector

**Decision:** `+3V3` reaches `J2` through a soldered wire between two pads,
`TP3` and `TP4`, rather than through copper. §3 forbids jumpers; this is the
exception, and it is recorded here so it reads as a decision rather than a
defect.

**Why copper could not do it:** `J1` pin 4 and its trace sit directly between
the `+3V3` rail and where the display connector had to go. On one layer there
is no way around that — a trace cannot cross another trace.

**Why the obvious workaround was worse.** The `+3V3` trace *can* be threaded
between `U1` pads 9 and 10: they are 2.54 mm apart, leaving 1.70 mm of gap,
and a 0.4 mm trace with 0.4 mm clearance needs 1.20 mm. DRC passes.

But it leaves roughly 0.25 mm of pour on each side of that trace, and the pour
is the ground return. `J1` pin 1 is the CC1101's ground. Threading `+3V3`
through that gap severs the ground plane between the radio and the rest of the
board, forcing its return current the long way round.

**That is the trade: a visible wire, or a compromised RF ground.** A wire link
is honest and costs ten seconds of soldering. A severed ground plane under a
433 MHz transceiver is invisible, passes every check, and shows up later as
poor range or an unstable receiver.

**Consequence to remember:** the display gets no power until `TP3`–`TP4` is
soldered. DRC will report `+3V3` as unconnected, correctly — the net genuinely
arrives in two pieces, and the link is off-board. Do not "fix" that warning by
routing through the pad gap.

**Rejected:** a second layer for one trace. §3's whole argument is that this
board does not need one, and reintroducing two-sided registration for a single
optional-display power line is not a trade worth making.

## Open items

- **ANATEL limits** for 433 MHz short-range transmission in Brazil. Not
  researched. **Blocking** for any transmission outside a dummy load.
- **CC1101 module pin order.** Varies between revisions. Check the silkscreen on
  the module in hand against the table in `docs/hardware.md` before routing;
  crossing VCC and GND destroys it.
- **Received-signal noise floor.** Unknown until it is on the air. The decoder's
  minimum-mark filter is a guess (`RADIO_RX_MIN_MARK_MS`) and wants tuning
  against the real band.

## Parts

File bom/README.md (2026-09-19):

# Bill of materials

`bom.csv` is the working BOM. Columns:

- **status** — `have` / `to buy` / `to make`
- **notes** — anything that would otherwise be lost between sessions

## Eleven parts to solder

Plus four mounting holes. None of it is surface-mount.

There is no `conditional` status in this BOM and no `phase 2` status either.
Every part is needed for the only version of the board that exists — nothing is
placed against a decision that has not been made yet, and nothing sits
unpopulated waiting for an open question to close.

## Sourcing: Brazil

Parts are chosen to be buyable locally (Mercado Livre, national distributors)
rather than imported. This is a selection criterion, not an afterthought — a part
that is optimal on paper but import-only costs weeks and customs hassle.

Every item is either already on hand or a generic through-hole part sold in any
Brazilian electronics shop: a tact switch, a buzzer, a ceramic cap, two headers.
Nothing here has a specific part number worth arguing about, and nothing is
SMD-only.

## Things to get right

1. **The buzzer must be PASSIVE.** This is the single most likely ordering
   mistake, because listings rarely say which they are and the two look
   identical. An active buzzer has its own oscillator and plays one fixed note
   whenever powered — `tone()` does nothing to it. The device needs two
   distinguishable pitches (700 Hz for your keying, 550 Hz for received signal),
   so an active buzzer breaks a feature rather than just sounding different.

   *How to tell them apart:* put a multimeter in resistance mode across the pins.
   A passive piezo reads a few ohms to a few hundred; an active module reads much
   higher or looks like a diode. If in doubt, buy one of each — they cost almost
   nothing.

2. **CC1101 module pin order.** Varies between module revisions. Check the
   silkscreen against the table in `docs/hardware.md` **before routing the
   board**, not before soldering — a wrong table means a wrong PCB. Crossing VCC
   and GND destroys the module.

3. **Buy the dummy load before the first transmit test.** It is listed as a part
   rather than as an accessory deliberately. Keying the radio with nothing
   attached reflects power back into the PA and can damage it, and the whip
   cannot be used until the ANATEL question is settled — so the dummy load is the
   only legal way to test transmit at all. It is a cheap SMA part; order it with
   everything else rather than discovering it is missing.

4. **Tact switch height.** The `_H5mm` variant sits taller, which matters once
   there is a case. Decide when the enclosure is modelled; the footprint is the
   same either way, so this is not blocking.

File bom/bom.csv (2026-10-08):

ref | qty | part | value | package | role | status | notes
U1 | 1 | ESP32-C3 Supermini |  | module | MCU — timing/decoding/radio control | have | 13 GPIO broken out (0-10 20 21); 3.3V native — matches CC1101 with no level shifting. Powers the board from its own USB-C
U2 | 1 | CC1101 module V2.0 | 433 MHz | module + SMA socket | RF transceiver — OOK TX and RX | have | SMA variant with detachable whip. SOCKETED not soldered — plugs into J1. CHECK SILKSCREEN PIN ORDER against docs/hardware.md before routing; varies by revision and crossing VCC/GND destroys it
J1 | 1 | Pin socket 2x4 female | 2.54mm | PinSocket_2x04_P2.54mm_Vertical | CC1101 module socket | to buy | FEMALE socket on the PCB — the module has MALE pins and plugs down into it. NOT PinHeader: different drill size, will not fit. Symbol: Conn_02x04_Odd_Even (generic — no dedicated CC1101 symbol needed)
J2 | 1 | JST XH 4-pin header | 2.50mm | JST_XH_B4B-XH-A_1x04_P2.50mm_Vertical | SSD1306 display connector | to buy | GND / +3V3 / GPIO9 (SCL) / GPIO8 (SDA) — matching the module on hand; other SSD1306 boards put VCC first, so check the silkscreen. JST XH is 2.50mm pitch, NOT 2.54 — the pads come off the board grid. Needs the matching crimp housing and pins. 0.95mm drill
SW1 | 1 | Tactile switch 6x6mm |  | SW_PUSH_6mm (THT, 4-pin) | Morse key | to buy | classic 6x6 tact switch; 4 pins but only 2 nets. Pick _H5mm variant if button height matters for the case. Debounced in firmware (15ms) — no RC network on the board
BZ1 | 1 | Magnetic buzzer 12mm |  | Buzzer_12x9.5RM7.6 (THT) | sidetone on TX + audio on RX | to buy | 12mm dia, 9.5mm tall, 7.6mm pin pitch. MUST BE PASSIVE — an active buzzer has its own oscillator and ignores tone(). Two pitches are load-bearing here: 700Hz your keying, 550Hz received
C1 | 1 | Capacitor | 100nF | C_Disc_D5.0mm_W2.5mm_P5.00mm (THT) | input decoupling on +5V | to buy | steadies the USB rail feeding the Supermini's regulator. Place near U1's 5V pin
C2 | 1 | Capacitor | 100nF | C_Disc_D5.0mm_W2.5mm_P5.00mm (THT) | CC1101 local decoupling on +3V3 | to buy | place close to J1 pin 1. The radio switches ~35mA at keying speed; this supplies that first instant locally
TP1 | 1 | Test point |  | TestPoint_THTPad_2.0x2.0mm_Drill1.0mm | probe point — +5V | to buy | 2mm pad, 1mm drill. Takes a probe tip, a wire, or a header pin
TP2 | 1 | Test point |  | TestPoint_THTPad_2.0x2.0mm_Drill1.0mm | probe point — GND | to buy | scope ground, next to TP1
TP3 | 1 | Solder pad |  | TestPoint_THTPad_2.0x2.0mm_Drill1.0mm | +3V3 jumper pad (board side) | to make | one end of the +3V3 wire link. See docs/decisions.md §14 — the rail cannot reach J2 on one layer without cutting the ground pour
TP4 | 1 | Solder pad |  | TestPoint_THTPad_2.0x2.0mm_Drill1.0mm | +3V3 jumper pad (display side) | to make | other end of the link. A short wire between TP3 and TP4 completes +3V3
H1-H4 | 4 | Mounting hole | M2 | MountingHole_2.1mm | board mounting — one per corner | to make | 2.1mm drill = M2 clearance. Plain hole, no copper pad. M2 chosen deliberately — smaller head keeps the corners clear
 | 1 | Antenna whip | 433 MHz | SMA male stub | RF | have | ships with the module; screws onto the board SMA socket. Detachable — case needs an opening. Never key the radio without it or a dummy load
 | 1 | Dummy load 50 ohm |  | SMA male | bench testing without emitting | to buy | REQUIRED before any transmit test. Use until ANATEL limits are settled — see docs/roadmap.md phase 4
 | 1 | PCB |  |  | main board | to make | fiber-laser engraved copper. SINGLE LAYER — one face only | no two-sided registration. 46 holes | 0.8-2.1mm | six sizes
 | 1 | Enclosure |  |  | case | to make | Onshape; exports to mechanical/

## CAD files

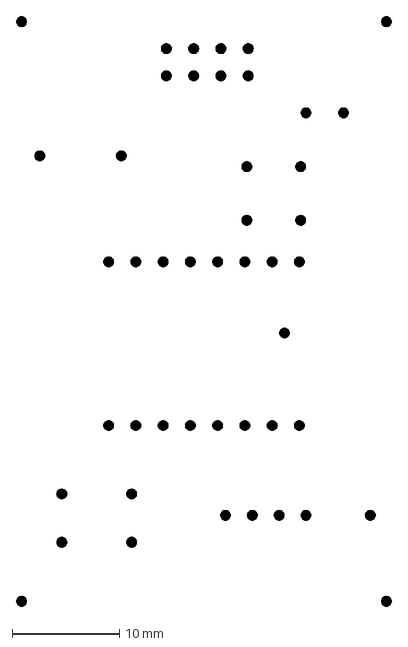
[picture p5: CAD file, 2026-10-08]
hardware/kicad/cc1101-morse/exports/cc1101-morse-DRILL-MARKS.dxf
35.0 x 55.0 mm

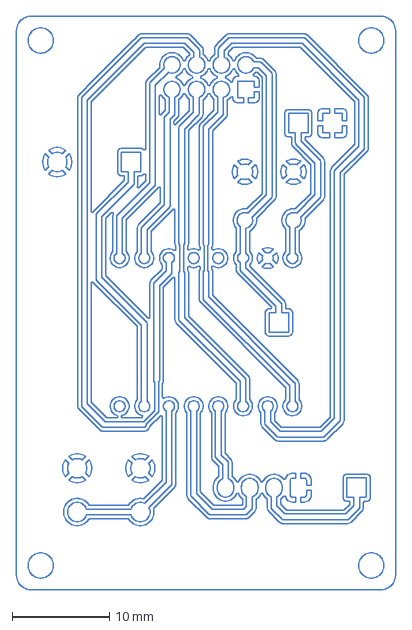
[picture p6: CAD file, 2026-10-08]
hardware/kicad/cc1101-morse/exports/cc1101-morse-B_Cu-MIRRORED.dxf
39.0 x 59.0 mm

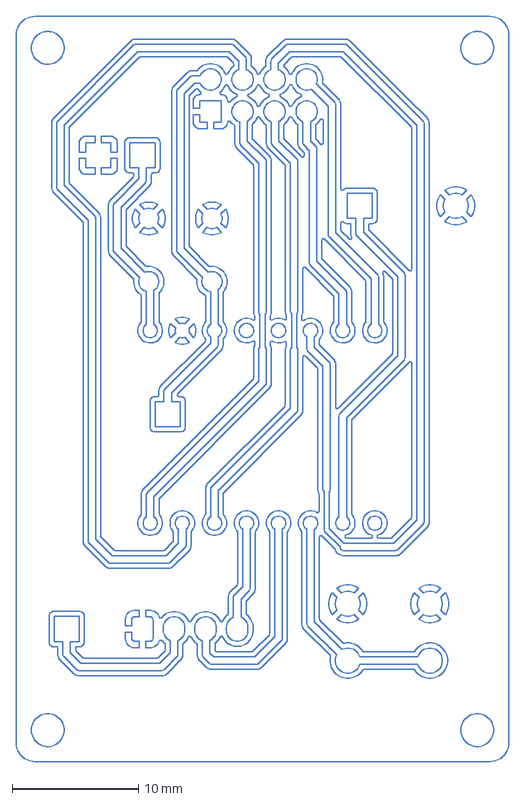
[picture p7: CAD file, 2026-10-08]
hardware/kicad/cc1101-morse/exports/cc1101-morse-B_Cu.dxf
39.0 x 59.0 mm

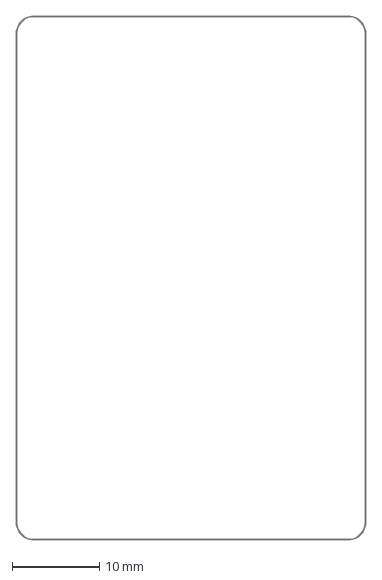
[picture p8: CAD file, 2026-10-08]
hardware/kicad/cc1101-morse/exports/cc1101-morse-Edge_Cuts.dxf
40.1 x 60.1 mm

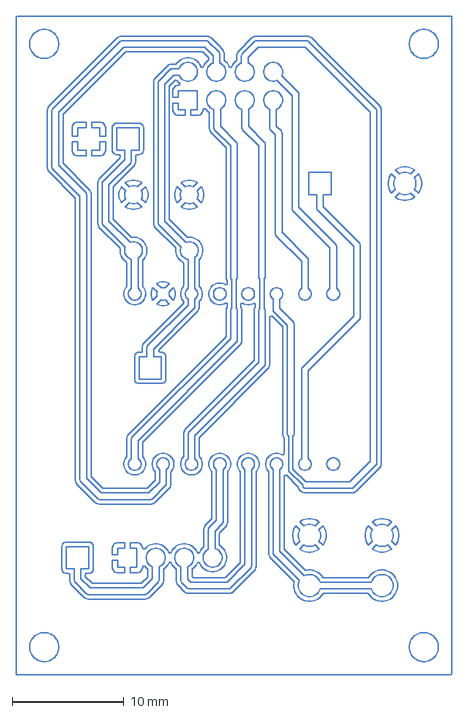
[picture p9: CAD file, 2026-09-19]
hardware/kicad/cc1101-morse/exports/copper-B_Cu.dxf
39.0 x 59.0 mm

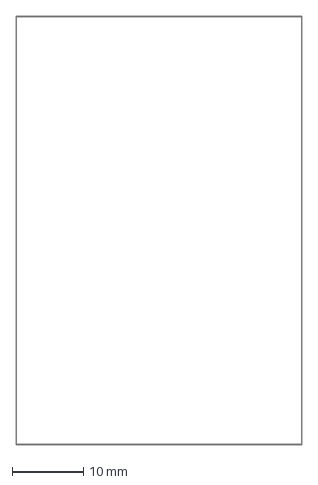
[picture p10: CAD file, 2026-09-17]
hardware/kicad/cc1101-morse/exports/outline-Edge_Cuts.dxf
40.1 x 60.1 mm

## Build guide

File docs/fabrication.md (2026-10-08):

# Fabrication — getting the board onto the fiber laser

The laser software (BSLApp, the EZCAD family that ships with JPT/Raycus
markers) imports **DXF**. KiCad exports DXF directly, so there is no
intermediate tool.

The files are committed in `hardware/kicad/cc1101-morse/exports/`. They are
generated, not source — but the point of this repo is that the board can be
made, and that means the laser's input should be here without needing KiCad
installed first. **Regenerate them after any board change**, with the commands
below.

## Generating the files

From `hardware/kicad/cc1101-morse/`:

```sh
# copper — what the laser removes. B.Cu: the copper is on the BACK.
kicad-cli pcb export dxf --mode-single -l B.Cu \
  --uc --erd --ev --ou mm --drill-shape-opt 0 \
  -o exports/copper-B_Cu.dxf cc1101-morse.kicad_pcb

# board outline — cut or scribe
kicad-cli pcb export dxf --mode-single -l Edge.Cuts \
  --uc --erd --ev --ou mm --drill-shape-opt 0 \
  -o exports/outline-Edge_Cuts.dxf cc1101-morse.kicad_pcb

# drill positions
kicad-cli pcb export drill --format excellon --excellon-units mm \
  -o exports/ cc1101-morse.kicad_pcb

# optional: a DXF picture of the hole positions, if drilling by eye.
# Not committed — it is 300 KB and says nothing the .drl does not.
#   ... --generate-map --map-format dxf ...
```

The flags that matter:

| Flag | Why |
|---|---|
| `--uc` (use contours) | plots shapes as **closed outlines** rather than centre lines. Without it the laser gets a stroke down the middle of each trace instead of its true edges, and every trace comes out the wrong width. |
| `--ou mm` | KiCad defaults DXF to **inches**. Import at the wrong unit and the board is 25.4× out. |
| `--erd --ev` | drops reference designators and values. They are silkscreen text, not copper — engraving them would eat into the traces. |
| `--drill-shape-opt 0` | no drill marks in the copper layer; holes are drilled mechanically, from the separate drill file. |
| `--mode-single` | one file at the path given, rather than a directory of per-layer plots. |

## What the three files are for

| File | Operation |
|---|---|
| `copper-B_Cu.dxf` | **engrave** — the copper to remove, on the back face |
| `outline-Edge_Cuts.dxf` | **cut** the 40 × 60 mm board out, or scribe it for snapping |
| `cc1101-morse.drl` | **drill** — 46 holes |

## The copper is on the back — mind the mirror

The stock is single-sided: copper on one face, bare substrate on the other.
Components sit on the **bare** face, their leads pass through, and they are
soldered on the **copper** face. So all copper lives on `B.Cu`, and `B.Cu` is
what gets engraved.

**KiCad draws every layer as seen from the top.** A `B.Cu` export is therefore
a view *through* the board. Put the copper face up on the laser bed and you are
looking at it from the other side — so the artwork has to be **mirrored**, or
every footprint lands reversed and nothing fits.

**Use the `-MIRRORED` files.** The plain exports are kept beside them for
checking against the KiCad view; they are *not* what goes on the laser.

| File | |
|---|---|
| `cc1101-morse-B_Cu-MIRRORED.dxf` | **engrave this** |
| `cc1101-morse-B_Cu.dxf` | reference, matches the KiCad top view |
| `cc1101-morse-Edge_Cuts.dxf` | **cut this** — unmirrored; the outline is symmetric, so it needs no flip |
| `cc1101-morse.drl` | drill, 46 holes |
| `cc1101-morse-DRILL-MARKS.dxf` | **drill by hand from this** — 1 mm dots at every hole |

Produce the mirrored pair with:

```sh
python3 scripts/mirror-dxf.py \
  exports/cc1101-morse-B_Cu.dxf exports/cc1101-morse-B_Cu-MIRRORED.dxf \
  --board cc1101-morse.kicad_pcb
```

**The axis comes from the board, not from the DXF.** The script reads the
Edge.Cuts outline out of the `.kicad_pcb` and mirrors about its X centre
(150.0 mm here). That matters: KiCad's DXF carries drawing-frame points far
outside the board, in units that differ between the GUI Plot dialog (inches by
default) and `kicad-cli --ou mm`. Every attempt to guess the board's extent
from the DXF alone got one of those cases wrong, and the failure is silent —
the artwork still looks like a board, just mirrored about the wrong line.

The script checks that the overall width is unchanged and refuses to write if
it is not, since a mirror that changes width has used the wrong axis.

KiCad's GUI can do it directly instead: File → Plot, tick **Mirrored plot** and
**Plot graphic items using their contours**, untick reference designators and
values. Watch the units there.

**The cheap check that catches a bad mirror:** the board is not symmetric. `J1`
sits at the top edge, `SW1` near the bottom, and the `vinilabs.cc` silkscreen
reads left to right. Put the artwork on screen and look at any asymmetric
feature — if the text reads backwards in the *mirrored* file, that is correct,
because you will be looking at the copper from the other side.

## Polarity: the laser removes what it marks

This is the one that ruins a board if it is got backwards.

`copper-B_Cu.dxf` contains the copper that must **remain** — traces, pads, and
the ground pour. A laser marks what you give it, so feeding this file directly
would burn away exactly the copper you wanted to keep.

In BSLApp, either:

- **invert the fill** so the marked region is the *background* rather than the
  shapes, or
- import the outline as an enclosing boundary and hatch the area *between* it
  and the copper shapes.

The ground pour makes this easier to sanity-check than it would otherwise be:
most of the board is copper, so the area the laser clears is a thin web around
the traces. **If the preview shows it clearing most of the board, the polarity
is inverted.**

## Hatching

Copper removal is an area operation, not an outline one — the fill settings
decide whether the copper actually comes off:

- **Hatch (fill) enabled**, line spacing around 0.02–0.05 mm.
- **Cross-hatch** (0° then 90°) gives a cleaner clear than one direction.
- Multiple passes at lower power beat one pass at high power: less heat into the
  substrate, less lifting at the trace edges.

Run a test coupon before committing the real board. The numbers above are a
starting point, not a recipe — they depend on the laser's wattage, the copper
thickness, and the laminate.

## Drill sizes

46 holes in six sizes:

| Size | Count | What |
|---|---|---|
| 0.80 mm | 4 | `C1`, `C2` |
| 0.84 mm | 16 | CC1101 socket (`J1`) |
| 0.95 mm | 4 | JST XH display header (`J2`) |
| 1.00 mm | 14 | test points, jumper pads |
| 1.10 mm | 4 | tact switch (`SW1`) |
| 2.10 mm | 4 | mounting holes (`H1`–`H4`) |

The drill file is Excellon, which BSLApp does not read — the holes are drilled
mechanically, not lasered.

**`cc1101-morse-DRILL-MARKS.dxf` is the one to use for hand drilling.** It is
one 1 mm filled dot per hole and nothing else: no traces, no pour, nothing to
read around. Print it or load it into the laser at low power to mark the
copper, then centre-punch and drill.

```sh
python3 scripts/drill-marks-dxf.py \
  exports/cc1101-morse.drl exports/cc1101-morse-DRILL-MARKS.dxf \
  --mirror 150.0
```

**`--mirror 150.0` is not optional here.** The copper is engraved mirrored
(see above), so marks generated from the raw drill file would land on the
wrong side of the board. 150.0 mm is the board's X centre, the same axis the
copper is mirrored about.

Every dot is the same size whatever the hole is. The file says *where* to
drill; the sizes are in the table below and in the `.drl`.

> [!NOTE]
> The mounting holes are **2.1 mm — M2 clearance**. This is deliberate, not a
> leftover: M2 screws keep the corner hardware small on a 40 × 60 mm board.

## Before exporting anything

Re-read this list each time; an export is only as good as the board behind it.

1. **Refill the zone** (`B`) and **re-run DRC until it is clean.** A zone that
   has not been refilled since the last routing pass reports a clearance
   violation against every net it touches, and the DXF will carry that same
   overlap into the copper.
2. **Check no trace crosses a mounting hole.** The autorouter could not read the
   holes' keepout areas — it logged `could not read keepout area of package
   MountingHole` — so it routed as if they were not there.
3. **Confirm 1:1 scale on import.** Measure the board in BSLApp: it must be
   40 × 60 mm. This is the check that catches a unit mismatch before it costs a
   piece of laminate.

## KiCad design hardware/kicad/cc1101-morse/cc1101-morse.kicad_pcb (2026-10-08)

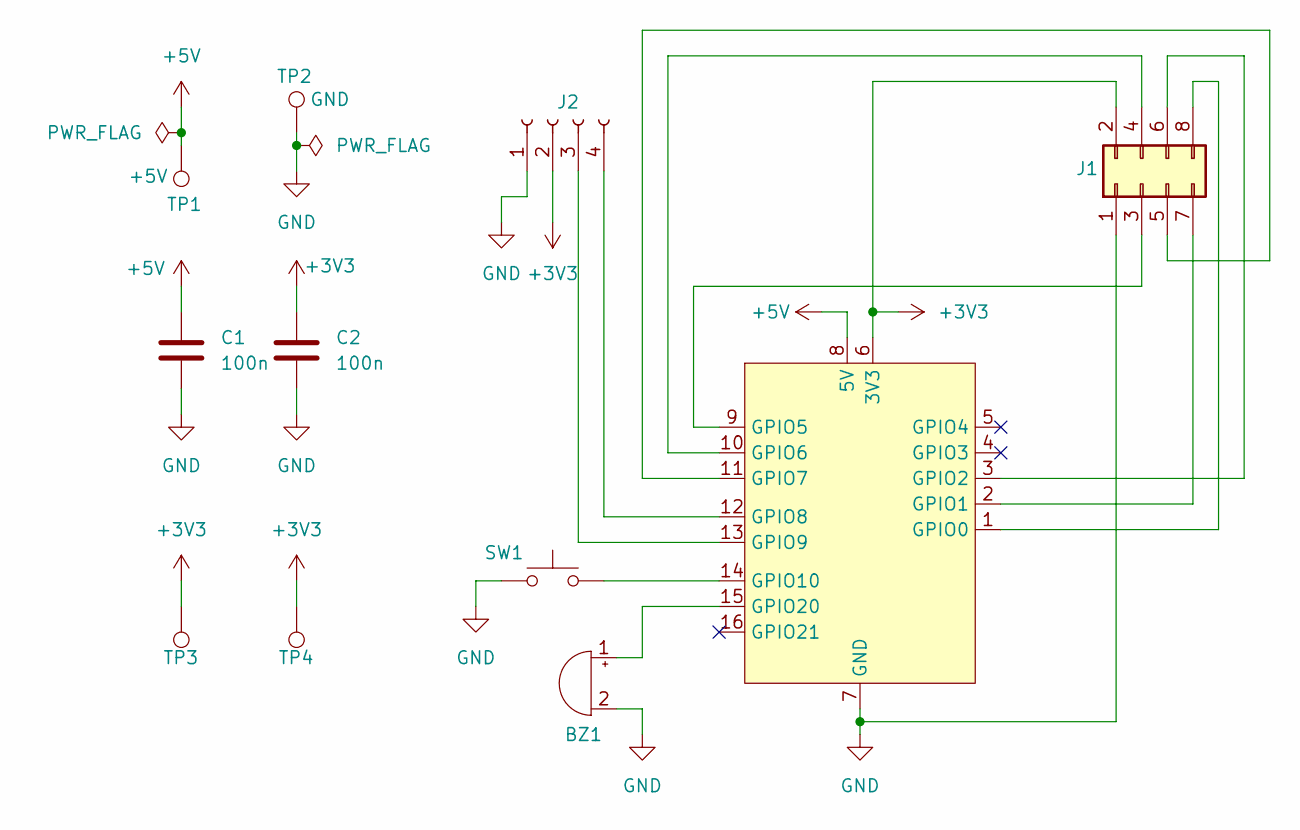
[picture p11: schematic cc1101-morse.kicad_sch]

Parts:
BZ1: Buzzer; Buzzer_12x9.5RM7.6
C1, C2: 100n; C_Disc_D5.0mm_W2.5mm_P5.00mm
J1: Conn_02x04_Odd_Even; PinSocket_2x04_P2.54mm_Vertical
J2: Conn_01x04_Socket; PinSocket_1x04_P2.54mm_Vertical
SW1: SW_Push; SW_PUSH_6mm
TP1: +5V; TestPoint_THTPad_2.0x2.0mm_Drill1.0mm
TP2: GND; TestPoint_THTPad_2.0x2.0mm_Drill1.0mm
TP3, TP4: +3V3; TestPoint_THTPad_2.0x2.0mm_Drill1.0mm
U1: ESP32-C3-SuperMini

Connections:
+3V3: C2.1, J1.2, J2.2, TP3.1 (1_1), TP4.1 (1_1), U1.6 (3V3)
+5V: C1.1, TP1.1 (1_1), U1.8 (5V)
GND: BZ1.2 (-), C1.2, C2.2, J1.1, J2.1, SW1.1, TP2.1 (1_1), U1.7 (GND)
unnamed: BZ1.1 (+), U1.15 (GPIO20)
unnamed: J1.3, U1.9 (GPIO5)
unnamed: J1.4, U1.10 (GPIO6)
unnamed: J1.5, U1.11 (GPIO7)
unnamed: J1.6, U1.3 (GPIO2)
unnamed: J1.7, U1.2 (GPIO1)
unnamed: J1.8, U1.1 (GPIO0)
unnamed: J2.3, U1.13 (GPIO9)
unnamed: J2.4, U1.12 (GPIO8)
unnamed: SW1.2, U1.14 (GPIO10)

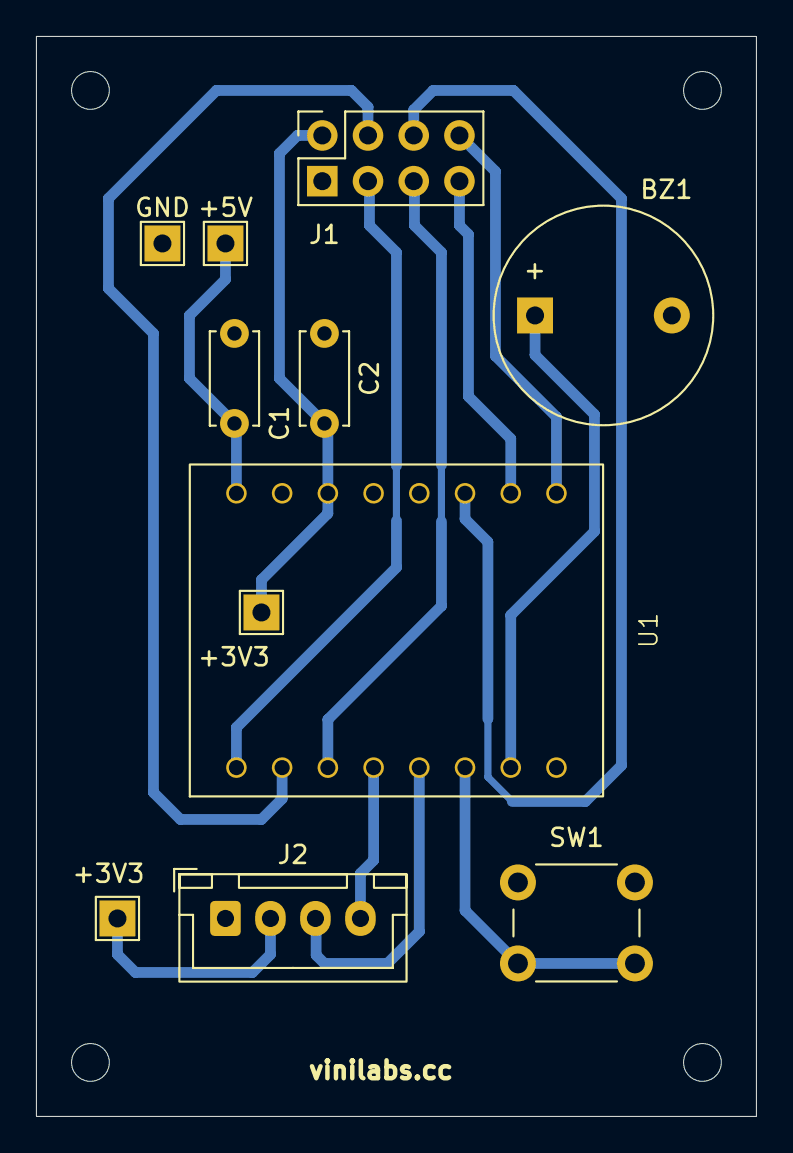
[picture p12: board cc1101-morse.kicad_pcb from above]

Board: 2 copper layers, 40.0 x 60.0 mm, 15 parts (0 on the bottom side), 13 nets.

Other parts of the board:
H1, H2, H3, H4: MountingHole_2.1mm

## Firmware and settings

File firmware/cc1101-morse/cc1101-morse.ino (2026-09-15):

// ============================================================
// CC1101 Morse — a handheld Morse transceiver
// ============================================================
//
// Key it and the characters go out over 433 MHz as OOK. Leave
// it idle and it decodes what another unit sends back.
//
// Hardware: ESP32-C3 Supermini + CC1101 module + key + buzzer.
// See docs/hardware.md for wiring.
//
// ------------------------------------------------------------
// RUNNING WITHOUT HARDWARE
// ------------------------------------------------------------
//
// The CC1101 is not required. radio.h defaults to
// RADIO_SIMULATE 1, which logs what it would key instead of
// driving the chip. Everything else — key timing, decoding,
// adaptive speed, sidetone — works identically.
//
// You can also drive it entirely from the serial monitor with
// no key wired: send '.' and '-' for symbols, space for a
// letter gap. Type `help` for the rest.
//
// Set RADIO_SIMULATE to 0 once the module is on the board.
//
// ------------------------------------------------------------
// BEFORE TRANSMITTING
// ------------------------------------------------------------
//
// Never key the radio with the antenna unscrewed — power
// reflects back into the PA and can damage it. Use a 50 Ohm
// dummy load for bench work.
//
// The ANATEL position on 433 MHz short-range transmission in
// Brazil has not been researched. Until it has, transmit into
// a dummy load only. See docs/roadmap.md phase 4.
//
// ============================================================

#include "morse_event.h"
#include "morse_tree.h"
#include "key.h"
#include "sidetone.h"
#include "radio.h"
#include "decoder.h"
#include "display.h"

// ------------------------------------------------------------
// Two decoders, one per direction. Same class, same code —
// they differ only in what feeds them and how their output is
// labelled. See morse_event.h.
// ------------------------------------------------------------

static Decoder txDecoder;   // what you are sending
static Decoder rxDecoder;   // what is coming in

// ------------------------------------------------------------
// The OLED, when one is attached.
//
// It mirrors what already goes to serial — nothing depends on
// it, and on the bare PCB (which has no OLED footprint) every
// call below is a no-op. See display.h.
// ------------------------------------------------------------

static void refreshStatus() {
  if (!oled.present()) return;
  char buf[24];
  snprintf(buf, sizeof(buf), "%2u wpm  %s  %s",
           key.wpm(),
           radio.mode() == RADIO_MODE_TX ? "TX" : "RX",
           radio.present() ? "RF" : "--");
  oled.setStatus(buf);
}

// TX holds the radio while you are keying and for a moment
// after, so the mode does not flap between every symbol. Once
// it expires the radio goes back to listening.
#define TX_HANG_MS 1200
static uint32_t lastKeyActivity = 0;
static bool     txHolding       = false;

// ------------------------------------------------------------
// Sending a stored message, for beacon and test use.
// ------------------------------------------------------------

static void sendString(const char* s) {
  uint16_t unit = key.unitMs();

  Serial.print(F("TX: "));
  Serial.println(s);

  radio.setMode(RADIO_MODE_TX);

  // The display has to be driven from inside this loop. sendString
  // blocks for as long as the message takes — 30 seconds at 5 wpm —
  // so loop() does not run and oled.tick() never gets a turn. Left
  // to itself the screen simply freezes for the whole transmission,
  // which looks exactly like a crash.
  char sent[DISPLAY_LINE_CHARS + 1] = "";
  uint8_t sentLen = 0;
  char symbols[8];

  for (const char* p = s; *p; p++) {
    if (*p == ' ') {
      if (sentLen < DISPLAY_LINE_CHARS) { sent[sentLen++] = ' '; sent[sentLen] = '\0'; }
      oled.setMessage(sent, nullptr);
      oled.showPartial("", MORSE_FROM_KEY);
      oled.renderNow();
      delay(unit * 7);          // word gap
      continue;
    }

    const char* code = morseCodeForChar(*p);
    if (!code) continue;        // silently skip punctuation

    uint8_t n = 0;
    for (const char* c = code; *c; c++) {
      // Show the symbol before sounding it, so the screen leads the
      // buzzer rather than trailing it.
      if (n < sizeof(symbols) - 1) { symbols[n++] = *c; symbols[n] = '\0'; }
      oled.showPartial(symbols, MORSE_FROM_KEY);
      oled.renderNow();

      radio.keyDown();
      sidetone.on(MORSE_FROM_KEY);
      delay(*c == '-' ? unit * 3 : unit);

      radio.keyUp();
      sidetone.off(MORSE_FROM_KEY);
      delay(unit);              // symbol gap
    }

    // Letter finished: commit it to the sent line and clear the
    // symbol display.
    if (sentLen >= DISPLAY_LINE_CHARS) {
      memmove(sent, sent + 1, sentLen - 1);
      sentLen--;
    }
    sent[sentLen++] = (*p >= 'a' && *p <= 'z') ? *p - 32 : *p;
    sent[sentLen] = '\0';
    oled.setMessage(sent, nullptr);
    oled.showPartial("", MORSE_FROM_KEY);
    oled.renderNow();

    delay(unit * 2);            // letter gap (1 already spent above)
  }

  radio.setMode(RADIO_MODE_RX);
  refreshStatus();
  oled.renderNow();
  Serial.println(F("TX: done"));
}

// ------------------------------------------------------------
// Serial commands — lets the whole thing be driven without a
// key or a radio attached.
// ------------------------------------------------------------

static void printHelp() {
  Serial.println();
  Serial.println(F("commands:"));
  Serial.println(F("  .         send a dot"));
  Serial.println(F("  -         send a dash"));
  Serial.println(F("  <space>   letter gap (commit the letter)"));
  Serial.println(F("  /         word gap"));
  Serial.println(F("  send TEXT transmit TEXT as Morse"));
  Serial.println(F("  clear     clear both messages"));
  Serial.println(F("  wpm N     set speed, fixed (disables adaptive)"));
  Serial.println(F("  auto      re-enable adaptive speed"));
  Serial.println(F("  tone      toggle the buzzer"));
  Serial.println(F("  buzzer    sweep test: passive or active?"));
  Serial.println(F("  rx        listen (default)"));
  Serial.println(F("  quiet     stop logging received symbols"));
  Serial.println(F("  loud      log received symbols"));
  Serial.println(F("  power N   TX power: 0=low 1=mid 2=full"));
  Serial.println(F("  status    radio registers and RSSI"));
  Serial.println(F("  help      this list"));
  Serial.println();
}

static void handleLine(String& line) {
  if (line == "help") {
    printHelp();

  } else if (line == "clear") {
    txDecoder.clearMessage();
    rxDecoder.clearMessage();
    oled.setMessage("", "");
    Serial.println(F("messages cleared"));

  } else if (line == "auto") {
    key.setAdaptive(true);
    Serial.println(F("adaptive speed on"));

  } else if (line == "tone") {
    sidetone.setEnabled(!sidetone.enabled());
    Serial.print(F("buzzer "));
    Serial.println(sidetone.enabled() ? F("on") : F("off"));

  } else if (line == "buzzer") {
    sidetone.sweepTest();

  } else if (line == "rx") {
    radio.setMode(RADIO_MODE_RX);
    txHolding = false;
    refreshStatus();
    Serial.println(F("listening"));

  } else if (line == "quiet") {
    rxDecoder.setVerbose(false);
    Serial.println(F("rx symbol logging off"));

  } else if (line == "loud") {
    rxDecoder.setVerbose(true);
    Serial.println(F("rx symbol logging on"));

  } else if (line == "status") {
    radio.dumpStatus();
    Serial.print(F("mode: "));
    switch (radio.mode()) {
      case RADIO_MODE_TX:   Serial.println(F("TX"));   break;
      case RADIO_MODE_RX:   Serial.println(F("RX"));   break;
      case RADIO_MODE_IDLE: Serial.println(F("idle")); break;
    }
    Serial.print(F("tx speed: "));
    Serial.print(key.wpm());
    Serial.print(F(" wpm (unit "));
    Serial.print(key.unitMs());
    Serial.print(F(" ms), "));
    Serial.println(key.adaptive() ? F("adaptive") : F("fixed"));
    Serial.print(F("rx speed: "));
    Serial.print(radio.wpm());
    Serial.println(F(" wpm (learned from the sender)"));

  } else if (line.startsWith("send ")) {
    String text = line.substring(5);
    text.trim();
    if (text.length() > 0) sendString(text.c_str());

  } else if (line.startsWith("wpm ")) {
    int w = line.substring(4).toInt();
    if (w >= 3 && w <= 30) {
      key.setAdaptive(false);
      key.setUnitMs(1200 / w);
      refreshStatus();
      Serial.print(F("fixed at "));
      Serial.print(w);
      Serial.println(F(" wpm"));
    } else {
      Serial.println(F("wpm must be 3..30"));
    }

  } else if (line.startsWith("power ")) {
    int p = line.substring(6).toInt();
    // Three useful points rather than raw PATABLE values: low
    // for bench work into a dummy load, full for range tests.
    static const uint8_t LEVELS[3] = {0x60, 0x84, 0xC0};
    if (p >= 0 && p <= 2) {
      radio.setPower(LEVELS[p]);
      Serial.print(F("power set to level "));
      Serial.println(p);
    } else {
      Serial.println(F("power must be 0..2"));
    }

  } else {
    Serial.print(F("unknown: "));
    Serial.println(line);
  }
}

static void handleSerial() {
  static String line = "";

  while (Serial.available()) {
    char c = Serial.read();

    if (c == '\n' || c == '\r') {
      line.trim();
      if (line.length() > 0) handleLine(line);
      line = "";
      continue;
    }

    // Single-character symbol input, acted on immediately —
    // but only when it is not part of a command word, so
    // "send SOS" is not eaten letter by letter.
    if (line.length() == 0) {
      if (c == '.') { txDecoder.feed(MORSE_DOT);  continue; }
      if (c == '-') { txDecoder.feed(MORSE_DASH); continue; }
      if (c == ' ') { txDecoder.feed(MORSE_LETTER_GAP); continue; }
      if (c == '/') {
        txDecoder.feed(MORSE_LETTER_GAP);
        txDecoder.feed(MORSE_WORD_GAP);
        continue;
      }
    }

    line += c;
  }
}

// ------------------------------------------------------------

void setup() {
  Serial.begin(115200);
  delay(500);

  Serial.println();
  Serial.println(F("================================"));
  Serial.println(F(" CC1101 Morse — transceiver"));
  Serial.println(F("================================"));

  key.begin();
  sidetone.begin();
  oled.begin();
  oled.splash("CC1101 Morse", "starting...");
  radio.begin();

  txDecoder.begin("tx | ");
  rxDecoder.begin("RX | ");

  radio.setMode(RADIO_MODE_RX);
  refreshStatus();
  oled.setMessage("", "");

  Serial.print(F("speed: "));
  Serial.print(key.wpm());
  Serial.print(F(" wpm (unit "));
  Serial.print(key.unitMs());
  Serial.println(F(" ms), adaptive"));

  if (!oled.present()) {
    Serial.println(F("display: none (buzzer + serial only)"));
  }

  printHelp();
  Serial.println(F("ready — press the key, or type . and -"));
  Serial.println(F("listening on 433.92 MHz"));
  Serial.println();
}

// ------------------------------------------------------------

void loop() {
  handleSerial();

  // --- transmit side -------------------------------------------

  MorseEvent kev = key.poll();

  if (key.isDown()) {
    bool wasHolding = txHolding;
    radio.keyDown();
    sidetone.on(MORSE_FROM_KEY);
    lastKeyActivity = millis();
    txHolding = true;
    if (!wasHolding) refreshStatus();   // RX -> TX
  } else {
    radio.keyUp();
    sidetone.off(MORSE_FROM_KEY);
  }

  if (kev != MORSE_NONE) {
    char done = txDecoder.feed(kev);
    if (done != MORSE_NO_LETTER) {
      oled.showLetter(done, MORSE_FROM_KEY);
    } else {
      oled.showPartial(txDecoder.partial(), MORSE_FROM_KEY);
    }
    lastKeyActivity = millis();
  }

  // Hand the radio back to receive once keying has stopped for
  // a moment. Without the hang time the mode would switch on
  // every symbol gap, and each switch costs a calibration.
  if (txHolding && !key.isDown() &&
      (millis() - lastKeyActivity) > TX_HANG_MS) {
    radio.setMode(RADIO_MODE_RX);
    txHolding = false;
    refreshStatus();
  }

  // --- receive side --------------------------------------------

  MorseEvent rev = radio.poll();

  // The RX sidetone only sounds when you are not keying, so
  // your own transmission is never interrupted by an incoming
  // one. sidetone.on() enforces this too; checking here keeps
  // it explicit.
  if (!key.isDown() && radio.present()) {
    if (radio.carrier()) {
      sidetone.on(MORSE_FROM_RADIO);
    } else {
      sidetone.off(MORSE_FROM_RADIO);
    }
  }

  if (rev != MORSE_NONE) {
    char done = rxDecoder.feed(rev);
    if (done != MORSE_NO_LETTER) {
      oled.showLetter(done, MORSE_FROM_RADIO);
    } else {
      oled.showPartial(rxDecoder.partial(), MORSE_FROM_RADIO);
    }
  }

  // Draw whatever the redraw limiter deferred. Without this the
  // last update of a burst can sit undrawn until the next event.
  oled.tick();
}

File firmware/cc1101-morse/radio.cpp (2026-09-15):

#include "radio.h"

Radio radio;

// ------------------------------------------------------------
// CC1101 registers — only the ones this design touches.
//
// The full map is large and mostly concerns the packet engine,
// which is switched off here. See the TI datasheet (SWRS061)
// if something below needs changing.
// ------------------------------------------------------------

#define CC1101_IOCFG2     0x00
#define CC1101_IOCFG0     0x02
#define CC1101_FIFOTHR    0x03
#define CC1101_PKTLEN     0x06
#define CC1101_PKTCTRL1   0x07
#define CC1101_PKTCTRL0   0x08
#define CC1101_FSCTRL1    0x0B
#define CC1101_FREQ2      0x0D
#define CC1101_FREQ1      0x0E
#define CC1101_FREQ0      0x0F
#define CC1101_MDMCFG4    0x10
#define CC1101_MDMCFG3    0x11
#define CC1101_MDMCFG2    0x12
#define CC1101_MDMCFG1    0x13
#define CC1101_MDMCFG0    0x14
#define CC1101_MCSM0      0x18
#define CC1101_FOCCFG     0x19
#define CC1101_AGCCTRL2   0x1B
#define CC1101_AGCCTRL1   0x1C
#define CC1101_AGCCTRL0   0x1D
#define CC1101_FREND0     0x22
#define CC1101_FSCAL3     0x23
#define CC1101_FSCAL2     0x24
#define CC1101_FSCAL1     0x25
#define CC1101_FSCAL0     0x26
#define CC1101_TEST2      0x2C
#define CC1101_TEST1      0x2D
#define CC1101_TEST0      0x2E

// Status registers (read with the burst bit set)
#define CC1101_PARTNUM    0x30
#define CC1101_VERSION    0x31
#define CC1101_RSSI       0x34
#define CC1101_MARCSTATE  0x35

// Command strobes
#define CC1101_SRES       0x30
#define CC1101_SCAL       0x33
#define CC1101_SRX        0x34
#define CC1101_STX        0x35
#define CC1101_SIDLE      0x36
#define CC1101_SFRX       0x3A
#define CC1101_SFTX       0x3B

#define CC1101_PATABLE    0x3E

#define CC1101_WRITE_BURST 0x40
#define CC1101_READ_SINGLE 0x80
#define CC1101_READ_BURST  0xC0

// GDO0 configurations.
//   0x0D — asynchronous serial data output (RX: pin follows carrier)
//   0x2E — three-state (TX: pin is an input, we drive it)
#define GDO0_CFG_ASYNC_DATA 0x0D
#define GDO0_CFG_HIGH_Z     0x2E

// ------------------------------------------------------------

bool Radio::begin() {
#if RADIO_SIMULATE
  present_ = true;
  Serial.println(F("[RADIO] SIMULATED — no CC1101 required"));
  Serial.println(F("        set RADIO_SIMULATE 0 in radio.h"));
  Serial.println(F("        once the module is wired"));
  return true;
#else
  pinMode(RADIO_PIN_CS,   OUTPUT);
  pinMode(RADIO_PIN_SCK,  OUTPUT);
  pinMode(RADIO_PIN_MOSI, OUTPUT);
  pinMode(RADIO_PIN_MISO, INPUT);

  // GDO2 is wired but unused. Held as an input so the ESP32-C3
  // never drives a pin the CC1101 might also drive.
  pinMode(RADIO_PIN_GDO2, INPUT);

  deselect_();
  digitalWrite(RADIO_PIN_SCK,  LOW);
  digitalWrite(RADIO_PIN_MOSI, LOW);

  delay(10);
  reset_();

  // A CC1101 answers 0x00 / 0x14 here. Anything else means the
  // wiring is wrong — almost always MISO/MOSI swapped, or the
  // module's pin order differing from the assumed one.
  uint8_t part = readStatus_(CC1101_PARTNUM);
  uint8_t ver  = readStatus_(CC1101_VERSION);
  present_ = (ver != 0x00 && ver != 0xFF);

  if (!present_) {
    Serial.print(F("[RADIO] no response (PARTNUM 0x"));
    Serial.print(part, HEX);
    Serial.print(F(" VERSION 0x"));
    Serial.print(ver, HEX);
    Serial.println(F(") — check wiring"));
    return false;
  }

  configure_();
  setPower(power_);
  setMode(RADIO_MODE_RX);

  Serial.print(F("[RADIO] CC1101 ready (VERSION 0x"));
  Serial.print(ver, HEX);
  Serial.println(')');
  return true;
#endif
}

// ------------------------------------------------------------
// Register table.
//
// Everything here serves one goal: turn the packet radio into a
// plain carrier switch. The comments say what each line is for,
// because a bare table of hex is unreadable six months later.
// ------------------------------------------------------------

void Radio::configure_() {
#if !RADIO_SIMULATE
  // --- carrier frequency: 433.92 MHz ---------------------------
  // f = (FREQ / 2^16) * 26 MHz, with a 26 MHz crystal.
  writeReg_(CC1101_FREQ2, 0x10);
  writeReg_(CC1101_FREQ1, 0xB0);
  writeReg_(CC1101_FREQ0, 0x71);

  // --- modulation ---------------------------------------------
  // MDMCFG2 = 0x30: OOK/ASK, no Manchester, NO sync word.
  // The sync word is the packet engine's way of knowing a
  // transmission started; we have no packets, so it must be off
  // or the receiver would wait forever for a frame that never
  // comes.
  writeReg_(CC1101_MDMCFG2, 0x30);

  // Channel filter bandwidth and data rate. In async mode the
  // data rate does not gate our timing — the firmware does —
  // but it still sets the receiver's filtering, so it wants to
  // be comfortably faster than the fastest keying.
  writeReg_(CC1101_MDMCFG4, 0xF5);
  writeReg_(CC1101_MDMCFG3, 0x83);
  writeReg_(CC1101_MDMCFG1, 0x22);
  writeReg_(CC1101_MDMCFG0, 0xF8);

  // --- packet engine: off -------------------------------------
  // PKTCTRL0 = 0x32: asynchronous serial mode, infinite packet
  // length, no CRC, no whitening. This is the line that turns
  // the chip into a carrier switch.
  writeReg_(CC1101_PKTCTRL0, 0x32);
  writeReg_(CC1101_PKTCTRL1, 0x00);   // no address check, no status bytes
  writeReg_(CC1101_PKTLEN,   0xFF);

  // --- GDO pins -----------------------------------------------
  // GDO2 is wired to a GPIO but unused by default (three-state).
  // See RADIO_GDO2_CFG in radio.h for what it could carry.
  writeReg_(CC1101_IOCFG2, RADIO_GDO2_CFG);
  writeReg_(CC1101_IOCFG0, GDO0_CFG_ASYNC_DATA);

  // --- AGC ----------------------------------------------------
  // OOK needs the AGC told what "off" looks like, since an
  // absent carrier is the signal. These are TI's recommended
  // OOK values: without them the receiver chases the noise
  // floor during spaces and reports a carrier that is not there.
  writeReg_(CC1101_AGCCTRL2, 0x07);
  writeReg_(CC1101_AGCCTRL1, 0x00);
  writeReg_(CC1101_AGCCTRL0, 0x91);

  writeReg_(CC1101_FSCTRL1, 0x06);
  writeReg_(CC1101_FOCCFG,  0x16);
  writeReg_(CC1101_FREND0,  0x11);

  // --- calibration --------------------------------------------
  writeReg_(CC1101_MCSM0,  0x18);   // auto-calibrate when leaving IDLE
  writeReg_(CC1101_FSCAL3, 0xE9);
  writeReg_(CC1101_FSCAL2, 0x2A);
  writeReg_(CC1101_FSCAL1, 0x00);
  writeReg_(CC1101_FSCAL0, 0x1F);

  writeReg_(CC1101_TEST2, 0x81);
  writeReg_(CC1101_TEST1, 0x35);
  writeReg_(CC1101_TEST0, 0x09);

  strobe_(CC1101_SCAL);
  delay(2);
#endif
}

// ------------------------------------------------------------

void Radio::setPower(uint8_t paValue) {
  power_ = paValue;
#if !RADIO_SIMULATE
  if (!present_) return;
  // In OOK, PATABLE[0] is the "off" level and PATABLE[1] the
  // "on" level — so the table is literally the key's two states.
  select_();
  transfer_(CC1101_PATABLE | CC1101_WRITE_BURST);
  transfer_(0x00);          // carrier off
  transfer_(power_);        // carrier on
  deselect_();
#endif
}
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

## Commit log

2026-09-13 Add project: docs, firmware, KiCad scaffolding
    A handheld 433 MHz Morse transceiver — the stripped-down sibling of
    Sparks. Same key, sidetone and Morse tree; no LED panel, no MAX7219.
    Dropping the panel is what makes the board simple, and the saving
    cascades: no panel means no MAX7219, which means nothing needs 5 V,
    which means no boost converter, which means no battery chain, which
    means the LED matrix's crossings are gone and one copper layer is
    enough. 35 parts become 8, 29 SMD parts become 0, two layers become
    one. Notably this also removes the HW-357's uncalibrated trimmer —
    a destructive-if-skipped assembly step.
    Firmware rests on one idea: a dot is a dot whether a finger made it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
    [bom.csv, cc1101-morse.kicad_pcb, cc1101-morse.kicad_sch]
2026-09-13 Correct schematic status: ERC clean, netlist verified
    The previous commit claimed the schematic shorted every net into one
    32-node net across the supply. That was wrong — a bad regex in the
    netlist check concatenated all 15 nets into one blob, and the empty
    power-symbol pin names offered as corroboration are normal in KiCad
    10 (the stock power library has them too).
    The schematic was correct all along. Verified: 15 nets, every
    connection matching the pin table — SPI on GPIO2/3/4, CSN GPIO1,
    GDO0 GPIO0, GDO2 GPIO7, key GPIO10, buzzer GPIO20, GPIO5/6/8/9/21
    unconnected.
    Remaining: C1 has no footprint, and J1 wants renaming to J2 since
    the BOM reserves J1 for the antenna.
    [cc1101-morse.kicad_sch]
2026-09-13 Correct CC1101 socket pin order to match Sparks
    The pin table assumed VCC on pin 1 and MOSI/SCK on 3/4. The real
    module — and Sparks, which wires one — has GND on pin 1, VCC on 2,
    and SCK before MOSI on 5/6. The supply pair was inverted, which is
    the mistake that destroys the module.
    Correct order, from the 433M silkscreen:
    1 GND 2 VCC 3 GDO0 4 CSN 5 SCK 6 MOSI 7 MISO 8 GDO2
    Firmware is unaffected: the GPIO-to-function assignments are
    unchanged, only which socket pin each one lands on.
    Also fixes the buzzer footprint name, which had a trailing "mm" the
    KiCad library does not use (Buzzer_12x9.5RM7.6, not ...RM7.6mm).
    [bom.csv, cc1101-morse.kicad_pcb, cc1101-morse.kicad_sch]
2026-09-13 Record design rules: 0.4 mm tracks, no net classes
    No net classes — nothing on this board needs different physical rules
    from anything else. Eight digital signals at Morse speeds plus power
    and ground; nothing fast, high-current, or impedance-controlled.
    0.4 mm sits wider than a fab house's 0.25 mm default, which is the
    right direction for laser etching: the cut widens as it bites, so the
    surviving copper is narrower than drawn.
    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
    [cc1101-morse.kicad_pcb, cc1101-morse.kicad_sch]
2026-09-13 Board: all parts placed, nothing routed
    Seven footprints on F.Cu, zero track segments — the snapshot to come
    back to if routing needs redoing from scratch.
    Footprints assigned: J1 the PinSocket for the CC1101, C1 a 5 mm disc
    cap, SW1 a 6 mm tact switch, BZ1 the 12 mm buzzer, two test points,
    and the local ESP32-C3 SuperMini.
    Design rules: 0.4 mm track and clearance, no net classes. Via
    settings are left at their defaults and will stay unused — this is a
    single-layer board, so a via has nowhere to go.
    [cc1101-morse.kicad_pcb]
2026-09-13 Reassign SPI pins so the traces stop crossing
    The first autoroute stalled with a net it could not finish. The cause
    was not the router: the straight-line paths between J1 and U1 crossed
    each other five times among seven nets, because the connector's
    left-hand pins were assigned to the MCU's right-hand pins and back
    again. On a two-layer board a crossing is a via; on one layer it is a
    trace that cannot be routed at all.
    Every SPI line here is bit-banged, so the mapping is free. Searched
    for the permutation with no crossings instead of guessing:
    MOSI GPIO2 -> GPIO6
    SCK GPIO3 -> GPIO5
    MISO GPIO4 -> GPIO2
    Zero crossings. The search was restricted to GPIO0-7 on purpose —
    allowing G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
    [cc1101-morse.dsn, cc1101-morse.kicad_pcb]
2026-09-13 Board: GND pour, mounting holes, J1 rewired to new pins
    The schematic now matches the reassigned SPI pins (MOSI GPIO6, SCK
    GPIO5, MISO GPIO2) — verified against the netlist, all eight J1 pins
    correct.
    Ground is a filled zone on F.Cu rather than the perimeter trace
    decisions.md §3 specified. The pour is the better choice here and the
    earlier objection to it was wrong: the board is 40x60 mm with 17
    thin traces, so there is no fragmentation risk, and the connection
    the autorouter could not make (BZ1.2 -> J1.2) is solved for free by
    both pads dropping into the fill. It also suits the process — a fiber
    laser removes copper, so leaving a pour is less etching, not more.
    Four mounting holes a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
    [cc1101-morse.dsn, cc1101-morse.kicad_pcb, cc1101-morse.kicad_sch]
2026-09-13 Annotate mounting holes H1-H4
    All four shared the placeholder REF**, which blocked Specctra DSN
    export ("Multiple footprints have the reference designator REF**").
    Numbered by position, top row first, left to right.
    [cc1101-morse.kicad_pcb]
2026-09-13 Rewrite docs to stand on their own
    The docs were framed throughout as a comparison against another
    board — decisions explained as "that project did X, here is why this
    one does not". Every decision now argues from its own merits instead.
    decisions.md is the main rewrite. §1 is no longer "no LED panel" but
    "no display", and explains the cost directly: a panel needs a driver
    IC, most are 5 V parts, 5 V needs level shifting and a boost
    converter, and the driver's addressing rarely matches the physical
    layout, which forces a second layer. The point is the chain, not that
    some other board went down it.
    Also adds §10 for the ground pour, which was decided in practice but
    never written down,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
    [cc1101-morse.kicad_pcb]
2026-09-13 Add schematic, PCB and 3D images to the README
    Three renders in media/: the schematic, the routed board, and the 3D
    view. A new "The board" section carries the schematic and layout;
    the 3D render sits at the top.
    Reconciles the docs with what was actually built, which had drifted:
    - J3, the battery header, was never placed. Removed from the BOM and
    from both docs; going portable now means soldering to the
    Supermini's own 5V/GND pins, which needs no board change.
    - The socket is J1 on the board, not J2 as the BOM had it.
    - TP1/TP2 and the four mounting holes were on the board but missing
    from the BOM.
    - hardware.md still carried a sketch of the perimeter ground trace
    that the pour r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
    [bom.csv]
2026-09-14 Document DXF export for the fiber laser
    BSLApp (the EZCAD family) imports DXF, and KiCad exports it directly,
    so there is no intermediate tool. docs/fabrication.md carries the
    exact kicad-cli commands and what each flag is for.
    The flags are not optional decoration:
    --uc plots closed contours. Without it the laser gets a stroke
    down the centre of each trace instead of its edges, and
    every trace comes out the wrong width.
    --ou mm KiCad defaults DXF to inches. Wrong unit = 25.4x board.
    --erd drops refdes text, which is silkscreen and would otherwise
    --ev be engraved into the copper.
    Also records the polarity trap, which is the one that destroys a
    board: t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
2026-09-15 Route the board by hand: DRC clean
    54 segments on F.Cu, no vias, ground poured. DRC reports 0 violations,
    0 unconnected, 0 schematic parity errors.
    Routed by hand after three autoroute attempts failed to produce a
    usable board. Freerouting could not see the mounting holes (it logged
    "could not read keepout area" on every run) and had no way to know
    that J1's GND pad needs a clear corridor for the pour to reach it —
    which is what left it isolated each time. Nine nets over ~227 mm was
    always inside hand-routing distance.
    [cc1101-morse.dsn, cc1101-morse.kicad_pcb]
2026-09-15 Keep mounting holes at M2
    2.1 mm, four corners — recorded as a deliberate choice rather than
    something to revisit. Smaller corner hardware suits a 40 x 60 mm
    board.
    Also drops two stale lines in hardware.md: a duplicated paragraph
    about the SPI assignment, and a note saying the pin numbers were "a
    starting proposal" open to adjustment during layout. They are final
    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
    [bom.csv]
2026-09-15 Add C2, decoupling the CC1101's own 3V3 rail
    C1 sits across +5V near the Supermini — input decoupling for the
    regulator, which is a real job but not the radio's. The CC1101 runs
    from +3V3 and had no local capacitor at all.
    C2 fills that gap. In TX the radio switches ~35 mA on and off at
    keying speed while SPI is bit-banged alongside it, so every mark is a
    step change in current. The regulator answers in microseconds and the
    trace to the socket has inductance; C2 supplies that first instant
    locally.
    Likely unnecessary at these currents, but the failure mode if it is
    needed and missing — intermittent SPI errors, or the radio dropping
    out only while transmitting — is much worse to diagn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
    [bom.csv, cc1101-morse.kicad_pcb, cc1101-morse.kicad_sch]
2026-09-15 Re-export for the laser; correct the hole count to 40
    C2 adds two holes, so the drill total went from 38 to 40. The count
    appeared in four places, two of them already stale at "~34".
    0.80 mm x4 C1, C2
    0.84 mm x16 J1
    1.00 mm x12 test points, headers
    1.10 mm x4 SW1
    2.10 mm x4 H1-H4
    [bom.csv]
2026-09-15 Adding vinilabs.cc
    [cc1101-morse.kicad_pcb]
2026-09-15 Add optional SSD1306 support and a buzzer type test
    The OLED is supported in firmware but stays off the PCB. decisions.md
    §1 rejected a display because of what one drags in — a driver IC, a
    second voltage, a second copper layer — and an I2C OLED brings none of
    that: own controller, 3.3 V, two wires. The objection was to the
    support chain, not to pixels. Putting it on the board would still cost
    a connector, holes and a case cutout for an optional part, so the
    firmware supports it and the board does not require it.
    Absence is a runtime property, not a compile-time one. Display::begin()
    probes 0x3C once; nothing there and every later call returns
    immediately — no retry, no timeout, no b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
    [cc1101-morse.ino, display.cpp, display.h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]
2026-09-15 Enable the radio: RADIO_SIMULATE 0
    The breadboard is wired to the schematic's pinout, which matches
    radio.h exactly — MOSI GPIO6, SCK GPIO5, MISO GPIO2, CSN GPIO1,
    GDO0 GPIO0, GDO2 GPIO7. Verified against the exported netlist before
    flashing.
2026-09-15 Document the USB CDC On Boot requirement
    It defaults to Disabled on the ESP32-C3, and with it off Serial goes
    to the UART pins rather than the USB port. The sketch runs normally
    and prints nothing the serial monitor can see.
    That cost real debugging time here: the radio was reporting
    "no response (PARTNUM 0xFF VERSION 0xFF) — check wiring" from the
    first boot, and none of it was visible. Every diagnostic this
    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
2026-09-15 Fix the CC1101 socket pinout to match the module
    J1 now carries the module's own order: GND, VCC, GDO0, CSN, SCK,
    MOSI, MISO, GDO2.
    Two things were wrong before. The supply pair was reversed — pad 1
    was +3V3 where the module has GND — so plugging a module into the
    board would have applied power backwards across it. And all six
    signals were offset, so nothing would have talked even had the module
    survived.
    Caught on the breadboard: status reported PARTNUM 0xFF VERSION 0xFF,
    MISO stuck high, which is what a module that is not driving the bus
    looks like.
    The signals cost nothing to fix. Every SPI line here is bit-banged,
    so no pin is special — radio.h just renames which GPIO is which
    f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
    [cc1101-morse.kicad_pcb, cc1101-morse.kicad_sch]
2026-09-15 Stop a floating GDO0 from locking up the device
    Two bugs, one symptom: the OLED would work, then freeze, and the key
    and buzzer would stop responding with it.
    With no CC1101 answering, GDO0 is an unconnected input — which is an
    antenna. It picks up noise and toggles, and Radio::poll() was timing
    those edges as if they were Morse. Each surviving edge became an
    event, each event redrew the OLED, and each redraw pushes the whole
    1 KB framebuffer over I2C at ~20 ms a time. The loop never got back
    to polling the key.
    1. poll() now returns immediately when present_ is false. There is
    nothing to listen to, so it does not listen.
    2. render() is rate-limited to one redraw per 50 ms, with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
    [cc1101-morse.ino, display.cpp, display.h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]
2026-09-15 Drive the display from inside sendString
    sendString blocks in delay() for the whole message — 30 seconds at
    5 wpm — so loop() never runs and oled.tick() never gets a turn. The
    screen froze for the entire transmission, which looks exactly like a
    crash and is why the device seemed to "work, then stop after a few
    seconds": it was fine until any send command.
    It now pushes the screen at every symbol and every letter, with
    renderNow() to bypass the rate limiter, since there is no loop to
    defer to. The symbol is drawn before it is sounded, so the screen
    leads the buzzer rather than trailing it.
    [cc1101-morse.ino]
2026-09-15 Set the radio pins to the corrected socket order
    MOSI GPIO2, SCK GPIO7, MISO GPIO1, CSN GPIO6, GDO0 GPIO5, GDO2 GPIO0
    — matching the module's own pinout as corrected in the footprint.
    This assignment was reverted earlier on the theory that GPIO0 and
    GPIO1 were unsafe on the ESP32-C3 and were breaking the display and
    key. That was wrong: the real cause was sendString blocking without
    redrawing the screen, fixed in c0ceacd. With that fixed, these pins
    work.
    Confirmed on the bench: CC1101 answers PARTNUM 0x0 VERSION 0x14, and
    "send SOS SOS SOS" at 5 wpm was received on an RTL-SDR in AM at
    433.92 MHz.
    [radio.h]
2026-09-15 Add J2 and J3: power and I2C breakout for an off-board OLED
    J3 brings GPIO8/GPIO9 out and J2 brings +3V3/GND, so an SSD1306 plugs
    into the finished board with four wires rather than flying leads to
    the module pins.
    decisions.md §11 argued the display should be supported in firmware
    but absent from the board, because a connector and a case cutout were
    too much for an optional part. Two 2-pin headers are a cheaper answer
    than the connector that argument rejected, and they stay unpopulated
    when no display is used.
    Board is now 44 holes, up from 40. DXF and drill re-exported.
    [bom.csv]
2026-09-17 Commit the laser export files
    The DXF and drill output now lives in the repo rather than being
    gitignored. They are derivatives, but a project whose whole point is
    that someone can make the board should carry what the machine eats —
    without needing KiCad installed to produce it first.
    Three files: the copper layer, the board outline, and the Excellon
    drill. The 300 KB DXF drill map is left out; it is a picture of what
    the 4 KB .drl already states exactly, and fabrication.md keeps the
    flags for anyone who wants it.
    Hole count corrected to 44 in the four places it was still written as
    40 — J2 and J3 added four.
    README brought up to date: the parts count, the OLED now having
    headers rath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
    [bom.csv, cc1101-morse.kicad_pcb, copper-F_Cu.dxf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]
2026-09-19 Move all copper to the back for single-sided laminate
    The stock has copper on one face and bare substrate on the other, so
    copper on F.Cu described a board that was never going to be made.
    Components sit on the bare face, leads pass through, and soldering
    happens on the copper face — the standard single-sided through-hole
    build.
    69 track segments and the ground pour moved to B.Cu. Nothing else
    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
    [cc1101-morse.kicad_pcb, copper-B_Cu.dxf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]
2026-09-19 Drop the stale F.Cu export
    Left over from before the copper moved to the back. It is artwork for
    a board that no longer exists, and the one file in exports/ that could
    quietly produce a wrong panel.
    [copper-F_Cu.dxf]
2026-09-19 Replace J2/J3 with one 4-pin display socket, plus a +3V3 wire link
    J2 is now a single 1x4 female socket — GND, +3V3, GPIO9 (SCL),
    GPIO8 (SDA) — so an SSD1306 plugs straight in instead of spanning two
    separate 2-pin headers. J3 is gone.
    +3V3 cannot reach it in copper. J1 pin 4 and its trace sit directly
    between the rail and the connector, and on one layer a trace cannot
    cross a trace. TP3 and TP4 are pads for a soldered wire link, which
    §3 otherwise forbids, so §14 records why this one is allowed.
    The workaround that looks better is worse. The rail can be threaded
    between U1 pads 9 and 10 — 1.70 mm of gap against the 1.20 mm a
    0.4 mm trace needs, and DRC passes. But it leaves ~0.25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
    [bom.csv, cc1101-morse.kicad_pcb, cc1101-morse.kicad_sch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]
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2026-09-19 Fixing routes
    [cc1101-morse.kicad_pcb]
2026-09-19 Widen tracks to 0.6 mm, except where they pass U1's pads
    Wider copper survives laser etching and handling better, and the
    board has room for it nearly everywhere.
    Nearly. U1's pads are on a 2.54 mm grid, so a 0.6 mm track threading
    between them leaves exactly 0.30 mm to each pad against a 0.40 mm
    rule — four clearance violations, all at the same geometry. Eight
    short segments now drop to 0.4 mm for the two or three millimetres
    they spend beside a pad and widen again after.
    Narrowing there rather than relaxing the clearance rule: the gap to
    the ground pour is also 0.4 mm, so lowering the netclass would have
    moved every trace on the board closer to ground to fix four local
    spots. And a 2 m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
    [cc1101-morse.kicad_pcb, copper-B_Cu.dxf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]
2026-09-19 Tidy the board; refresh the renders
    Removes a 0.06 mm +3V3 fragment left behind by an earlier track
    split. Electrically nothing, but DRC flagged it as a dangling end and
    the laser would have etched it as a copper spur.
    Schematic changed too, though its netlist is byte-identical — the
    edit was cosmetic. All three renders regenerated.
    DRC back to the three documented exceptions: the TP4/U1 courtyard
    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
    [cc1101-morse.kicad_pcb, cc1101-morse.kicad_sch, copper-B_Cu.dxf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]
2026-09-23 Changing ESP32 pad shapes from circular to oval to improve etching
    [cc1101-morse.kicad_pcb]
2026-09-24 Adding 3mm rounded corners and exporting cc1101-morse-B_Cu.dxf
    [cc1101-morse-B_Cu.dxf, cc1101-morse.kicad_pcb]
2026-10-01 Disabling island removal mode to improve etching
    [cc1101-morse-B_Cu.dxf, cc1101-morse-Edge_Cuts.dxf, cc1101-morse.kicad_pcb]
2026-10-08 Add a mirrored B.Cu export for the laser
    The copper is on B.Cu and KiCad draws every layer from the top, so
    the plain export is a view through the laminate. Engraving it puts a
    reversed image on the copper and nothing fits.
    cc1101-morse-B_Cu-MIRRORED.dxf is the file to engrave. The unmirrored
    one stays beside it for checking against the KiCad view.
    scripts/mirror-dxf.py produces it from any KiCad DXF export. It
    mirrors only board geometry: KiCad's DXF carries a few drawing-frame
    points far outside the board, and flipping those drags the extents
    out — the first attempt here turned a 39 mm board into 169 mm. The
    script leaves them alone and verifies the width is unchanged, exiting
    non-zero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
    [cc1101-morse-B_Cu-MIRRORED.dxf, cc1101-morse-B_Cu.dxf, cc1101-morse-Edge_Cuts.dxf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]
2026-10-08 Keep the laser files in exports/ only
    Two DXFs had landed in the KiCad project directory alongside the
    copies in exports/ — same board, different plot settings, four files
    where there should be three. Git read them as renames in the previous
    commit, which is why they appeared a directory up.
    Removed the strays. exports/ is the one place to look:
    cc1101-morse-B_Cu-MIRRORED.dxf engrave this
    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
    [cc1101-morse-B_Cu.dxf, cc1101-morse-Edge_Cuts.dxf]
2026-10-08 Mirror about the board centre, not a guessed extent
    Island removal is now set to "never", so the pour keeps copper that
    would previously have been deleted. DRC reports ten isolated_copper
    warnings as a result — expected, and a consequence of the setting
    rather than a defect.
    Regenerating the exports exposed a real bug in mirror-dxf.py. It had
    been inferring the board's extent from the DXF by assuming board
    coordinates fell in 1..100, which held for the GUI's inch exports and
    broke immediately on millimetre ones at 130..170. Two further
    heuristics — density bucketing, then gap walking — each failed on one
    case or the other.
    It now takes the axis from the .kicad_pcb's Edge.Cuts outline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
    [cc1101-morse-B_Cu.dxf, cc1101-morse-Edge_Cuts-MIRRORED.dxf, cc1101-morse-Edge_Cuts.dxf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]
2026-10-08 Keep plotted DXFs out of the KiCad project directory
    KiCad's Plot dialog writes to the project directory by default, so
    exports keep landing beside the .kicad_pcb as well as in exports/.
    Two copies of the same artwork under different names is how the wrong
    one reaches the laser.
    Ignored, so only exports/ is tracked.
    [cc1101-morse-B_Cu.dxf, cc1101-morse-Edge_Cuts.dxf]
2026-10-08 Removing redundant file
    [cc1101-morse-Edge_Cuts-MIRRORED.dxf]
2026-10-08 Mirror only the ENTITIES section
    ShareCAD hung forever on the mirrored DXF while loading the plain one
    fine — a good signal that the file was malformed rather than the
    viewer being slow.
    Group codes 10 and 11 mean "X coordinate" inside an entity, but the
    same numbers appear in the HEADER and TABLES sections as ordinary
    values. The script was rewriting those too, corrupting table entries
    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
    [cc1101-morse-B_Cu-MIRRORED.dxf, cc1101-morse-Edge_Cuts-MIRRORED.dxf]
2026-10-08 Round the board corners; J2 becomes a JST XH
    2 mm radius on all four corners. The ground pour had to be refilled
    after — it was still square and overhung the new edge, which DRC
    caught as a board-edge clearance violation.
    J2 is now a JST XH 4-pin header rather than a bare pin socket:
    polarised, latching, and it will not shake loose. Pitch is 2.50 mm,
    not 2.54, so its pads sit off the board grid — normal for the part,
    and worth knowing before anyone tries to align them.
    Drill gains a sixth size: 0.95 mm for the XH pins, with 1.00 mm
    dropping from 18 to 14. Still 46 holes.
    Exports regenerated. Only B_Cu is mirrored, as asked — the outline is
    symmetric about both axes, so the cut file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
    [bom.csv, cc1101-morse-B_Cu-MIRRORED.dxf, cc1101-morse-B_Cu.dxf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]
2026-10-08 Add a drill-marks DXF for hand drilling
    One 1 mm filled dot per hole and nothing else — no traces, no pour,
    nothing to read around while lining up a drill. KiCad cannot export
    this directly; it plots layers, and there is no drill-marks layer.
    The positions are already in the .drl, so the script reads them from
    there.
    Mirrored about x=150.0 to match the engraved copper. That is not
    optional: the copper goes on mirrored, so marks made from the raw
    drill file would land on the wrong side of the board. The script
    takes --mirror rather than assuming it, since the same tool is useful
    for unmirrored boards.
    Discs are drawn as fans of SOLID triangles. HATCH would be tidier but
    is read inconsiste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
    [cc1101-morse-DRILL-MARKS.dxf]
